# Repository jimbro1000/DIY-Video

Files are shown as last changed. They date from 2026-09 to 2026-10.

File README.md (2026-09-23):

# DIY Video #

The DIY Video project is an attempt to define a reusable video "chip" with
modular components. The concept is to limit the design to regular 74LS
ICs.

The goal is a design that can be plugged into most (if not all) 8-bit
computers.

The minimal design permits a system that can switch between a simple
text mode and bitmap mode with a usable screen resolution of 320x200 pixels.
Output is unterminated RGB that can be transformed into an appropriate
format as required

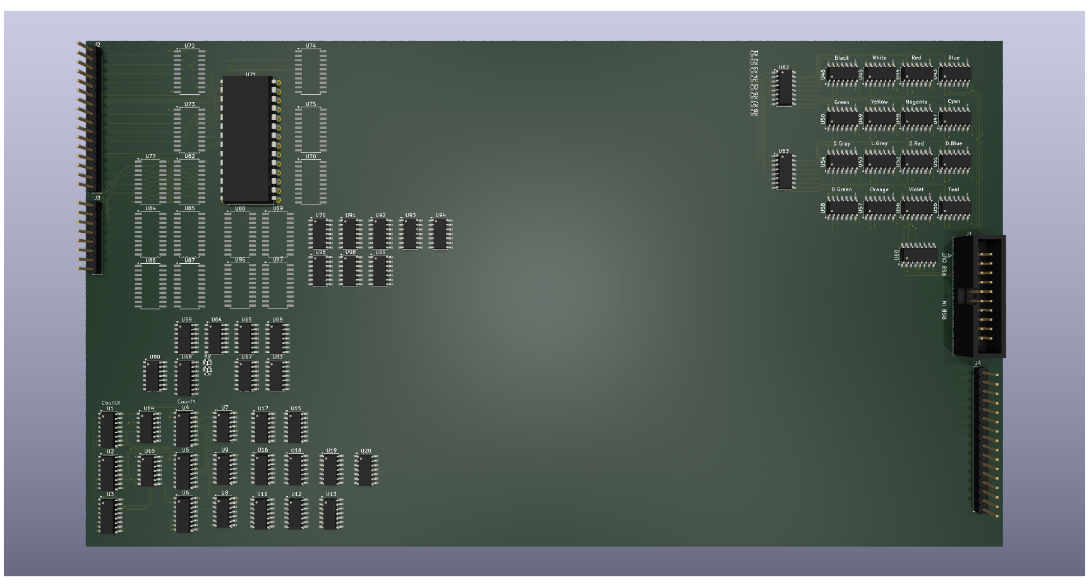
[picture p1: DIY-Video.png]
Render of PCB


## Design Concepts ##

Each major component of the video system is deliberately isolated so
that a change in one area should not require rework elsewhere. This rule
is broken in some places but is respected as much as possible

The core of the system is a pair of counters that track the X and Y 
position of the "beam". These counters are then used to define the
frame timing (sync and blank) and the viewport position on the screen.

The frame timing also controls what video source makes it to the output
as the sync and blank phases of the signal fall under timing control.

The bitmap renderer uses the pixel counters to generate a palette index
based on either a 1, 2 or 4 bit length value. The index is turned into
RGB using a separate pair of modules that generate 16 distinct RGB values
and a decoder that switches the RGB output between the 16 different
palette options

Independently to all this is the memory controller, actually a repeated
module that provisions different, parallel rendering mechanisms. From
the perspective of the video system each has its own address register
and can be accessed independently of the others - so the bitmap, tile
and sprite data can be operated separately without impacting the timing
of the other.

Externally the different blocks of memory needed to be mapped into the
hosts address space. To facilitate this the different memory blocks
are first selected by a device select signal and are then (optionally)
paged to ease the host burden. 

This approach makes the internal address very wide - each memory block is
a maximum of 32K and with distinct address buses and data buses the burden
for the video system is high but the length and distribution of those
buses can be minimised leaving just the palette values as the the 
interconnect rather than wide data and address buses

The current design respects five different addressable sub-devices
Bitmap memory  
Tile memory  
Sprite memory  
Font generator  
Control registers  

Only the bitmap and control registers are currently implemented.

The font generator in initial design iterations will be a simple eprom that
does not require external addressing

## Roadmap ##

### Stage 1 ###

The initial design stage is to define the hardware and interfaces, the broad
timing requirements and what modules are dependent. The goal is to achieve
a design that can be tested in self-contained modules, that together can
implement a basic bitmap based video generator.

### Stage 2 ###

The initial design will be verified and refined to prove that the modules work.
No attempt to integrate the modules will be attempted at this stage. Signal
and power requirements will be added to the design

### Stage 3 ###

Modules will be implemented as independent PCBs to be re-verified. A backplane
to integrate the modules will be needed with scope to extend the design to 
include other sub-systems

### Stage 4 ###

This is the first opportunity to integrate the entire set of modules defined.
To provide a usable display that can be verified the system will also need
to be integrated with a host computer to drive the video memory content

## Test Progress ##

### Simulation ###

* Position Counters (verilog, CRUMB)
* ViewPort (Verilog)
* Bitmap Data Counters (Verilog)

## License ##

This project is licensed under CC BY-SA 4.0
<https://creativecommons.org/licenses/by-sa/4.0/>

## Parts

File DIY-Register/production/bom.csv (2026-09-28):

Designator | Footprint | Quantity | Value | LCSC Part #
C1, C2 | 0603 | 2 | 10nF
D1, D2, D3, D4, D5, D6, D7, D8 | 0603 | 8 | LED_Small_Filled
J1 | PinHeader_1x10_P1.27mm_Vertical | 1 | Register0
J2 | PinHeader_1x10_P1.27mm_Vertical | 1 | XDBus
J3 | PinHeader_1x08_P1.27mm_Vertical | 1 | XDBus
RN1, RN2 | R_Array_Concave_4x0402 | 2 | 100R
U1 | SO-20_5.3x12.6mm_P1.27mm | 1 | 74LS374
U2 | SO-20_5.3x12.6mm_P1.27mm | 1 | 74LS244

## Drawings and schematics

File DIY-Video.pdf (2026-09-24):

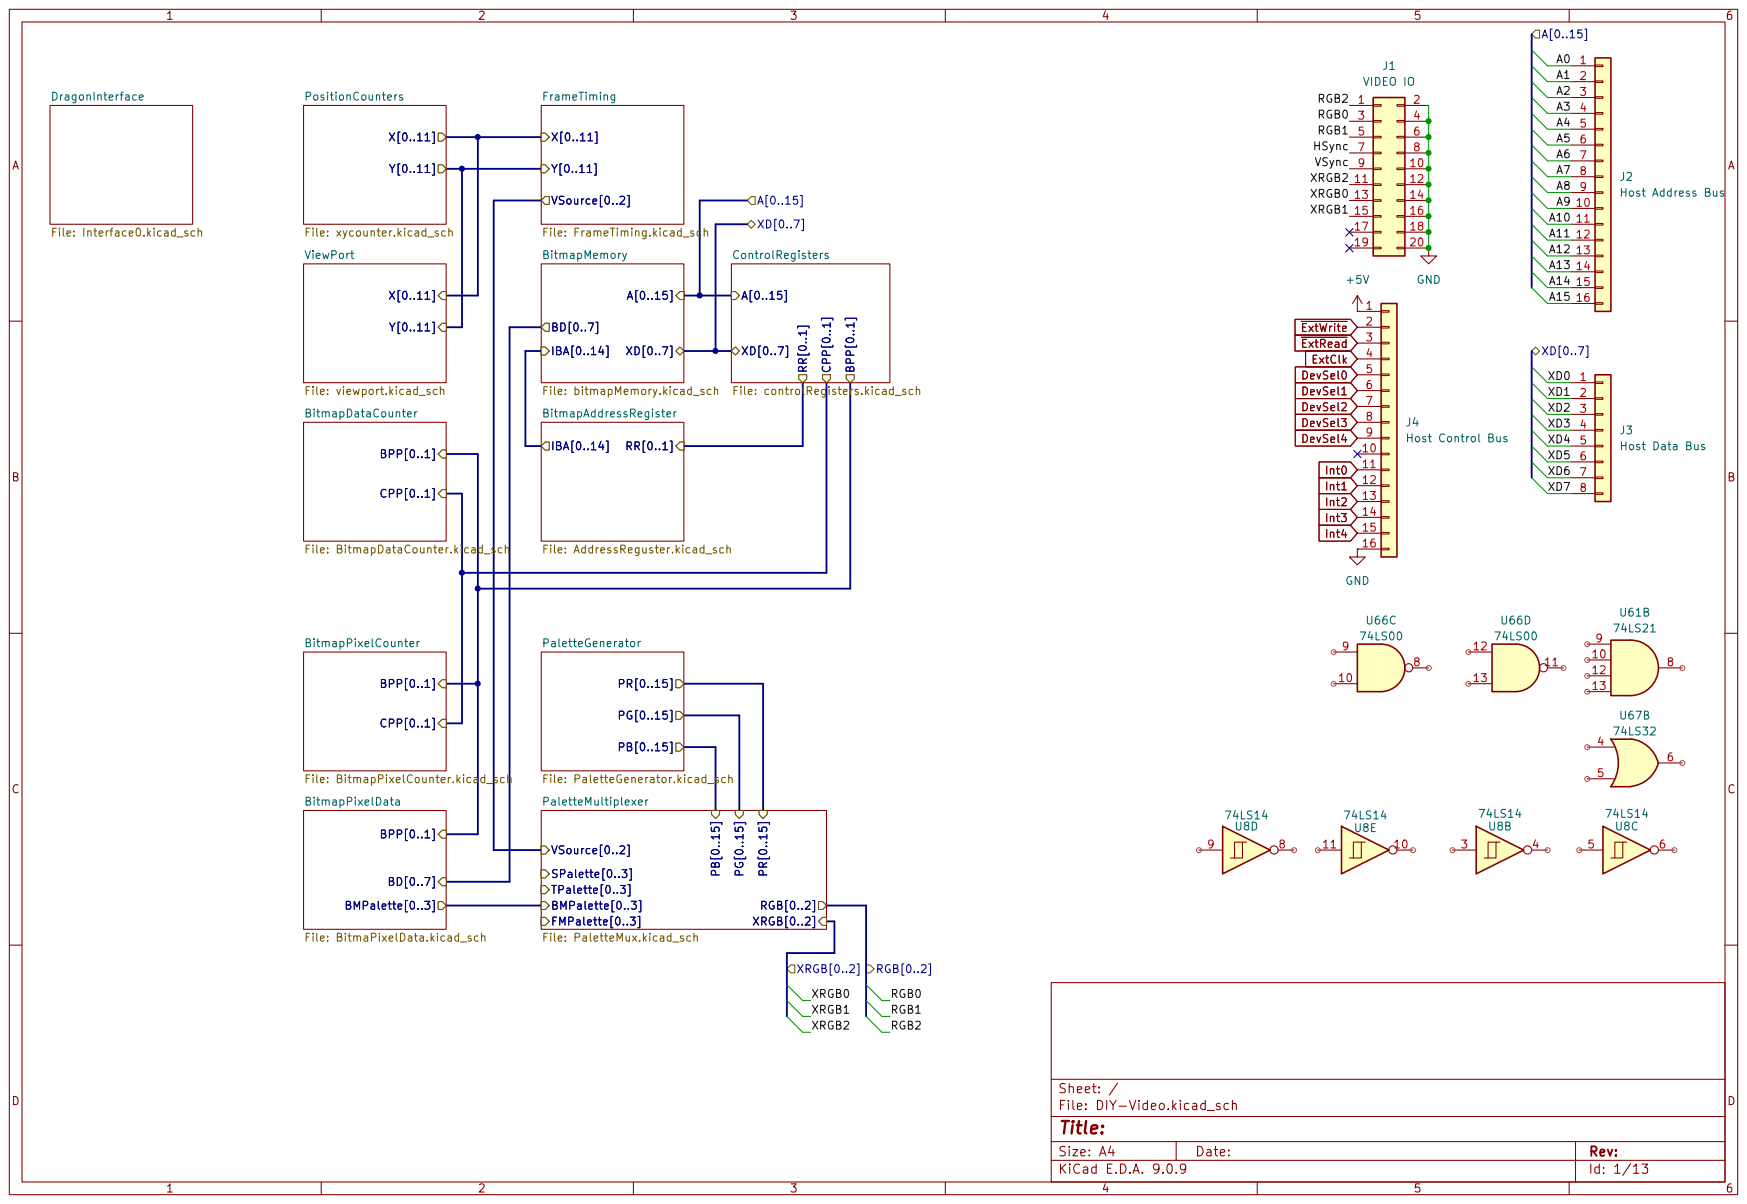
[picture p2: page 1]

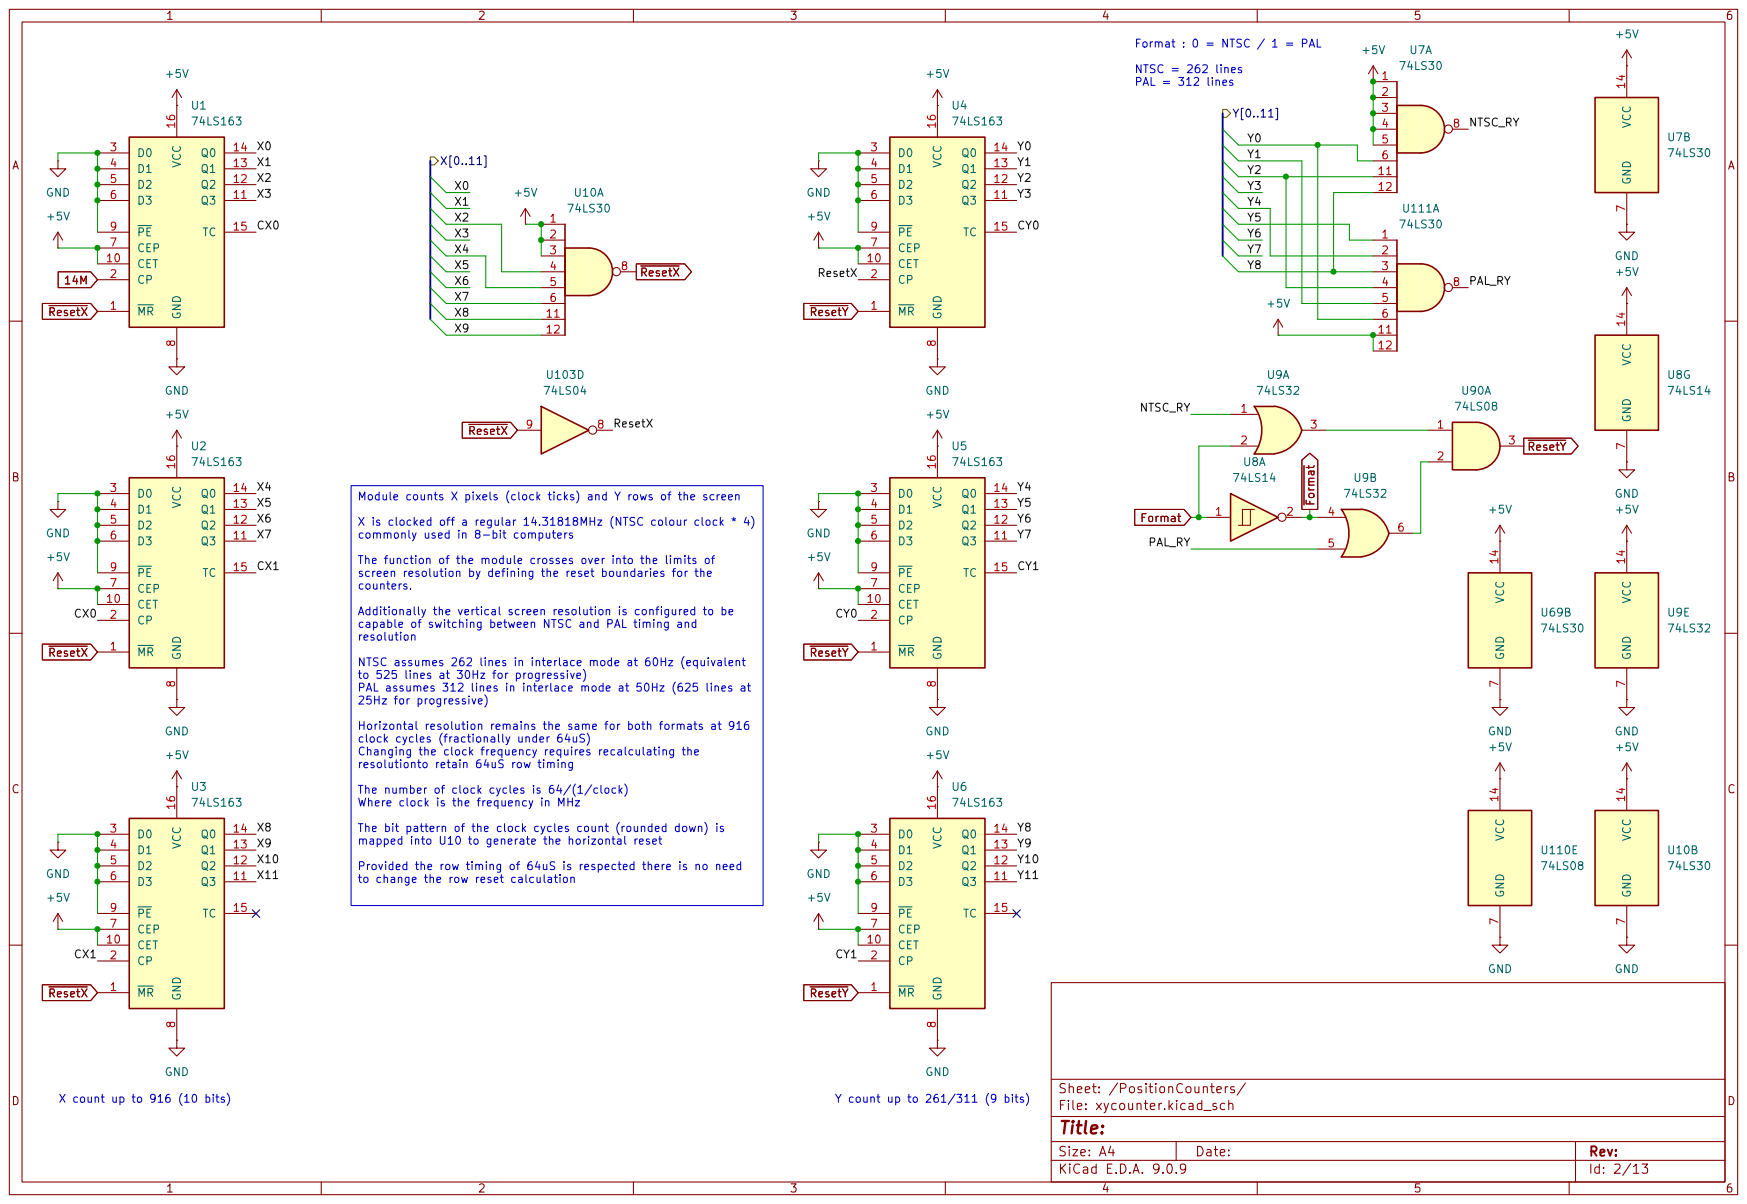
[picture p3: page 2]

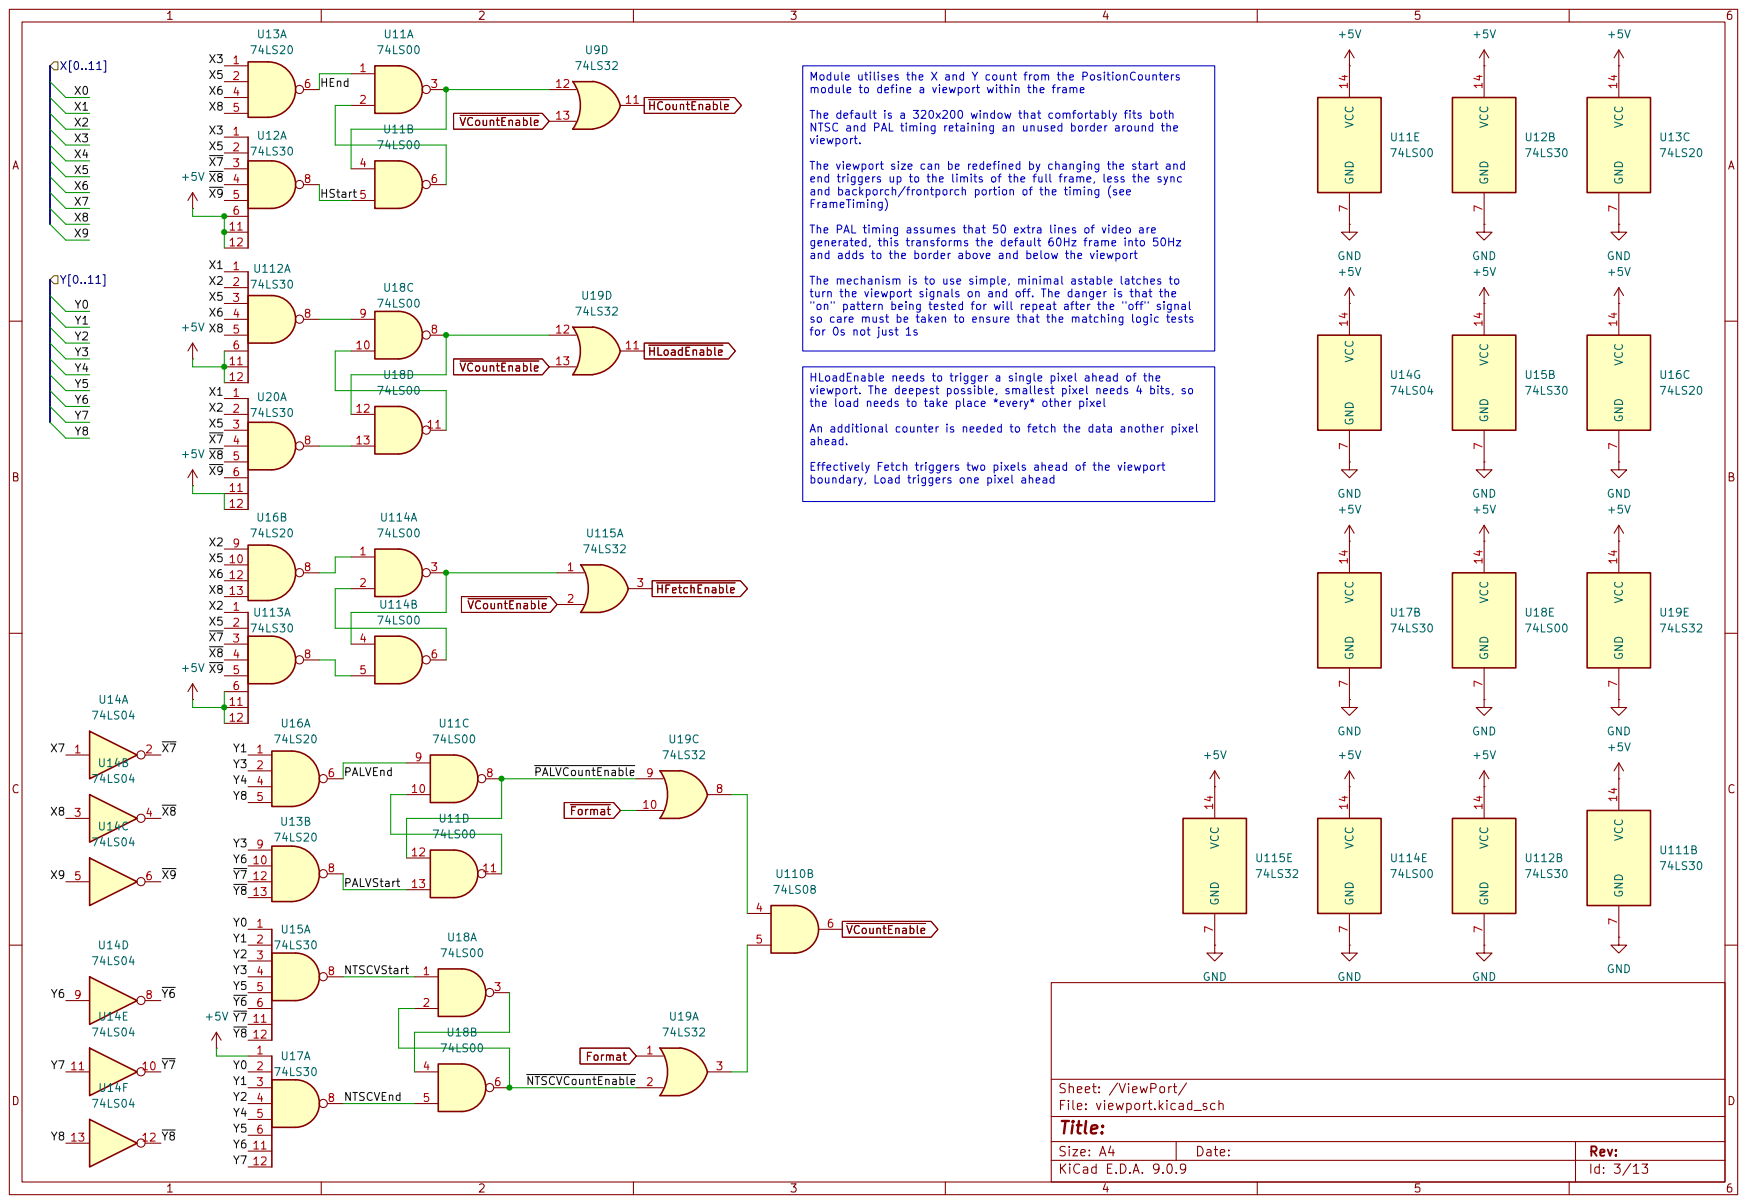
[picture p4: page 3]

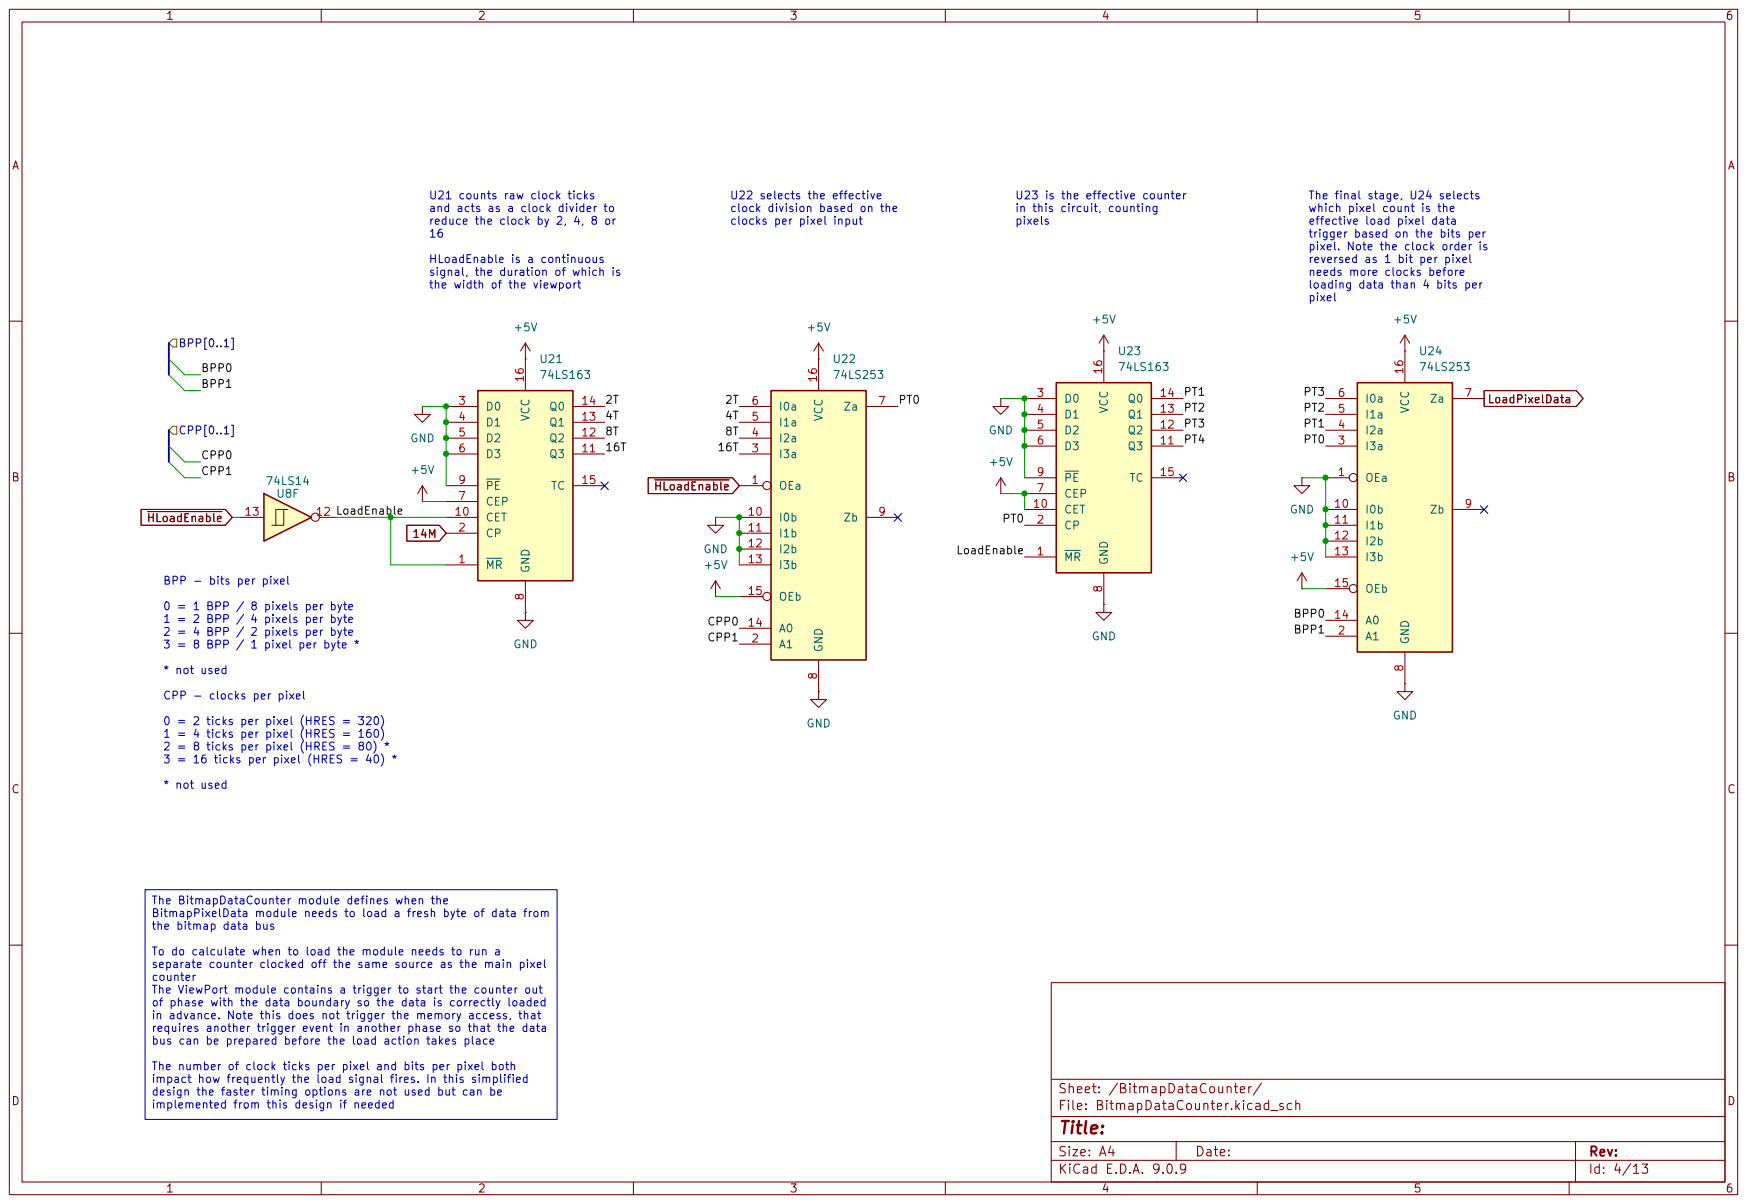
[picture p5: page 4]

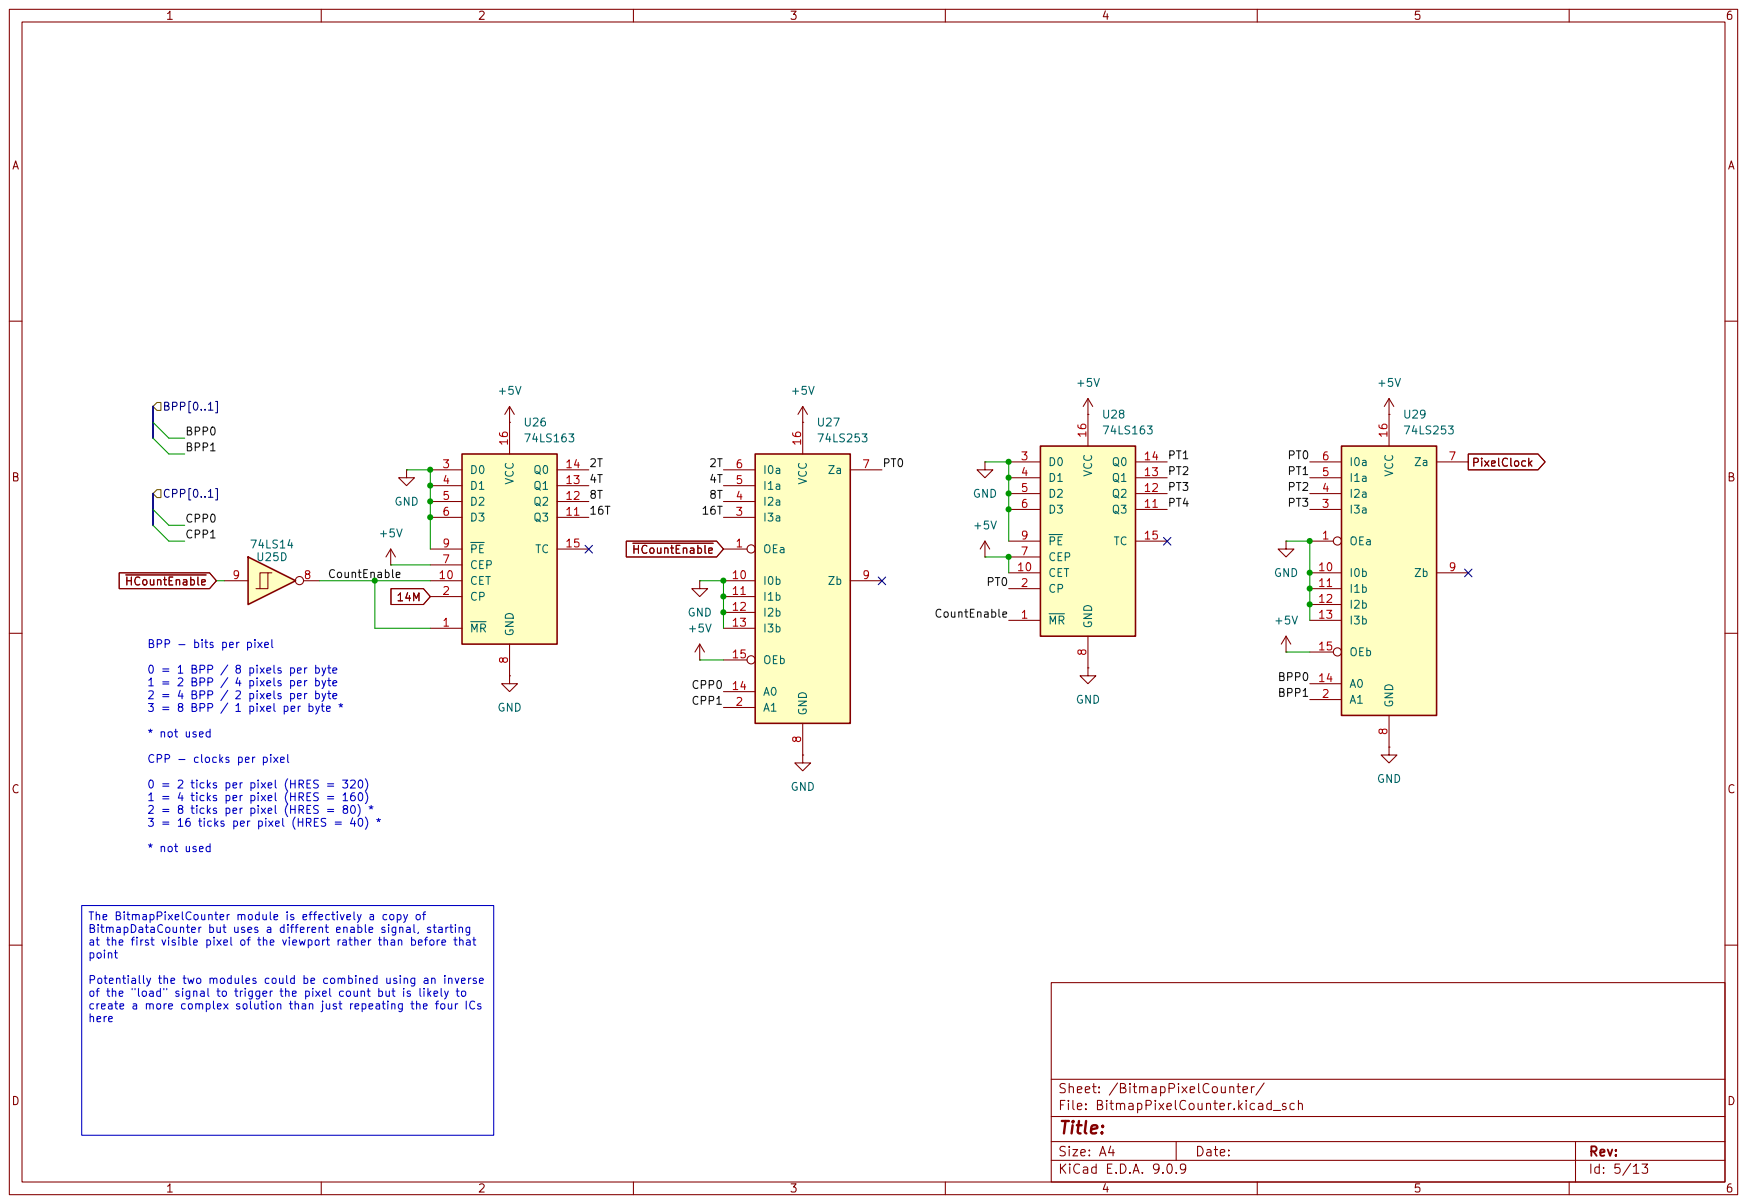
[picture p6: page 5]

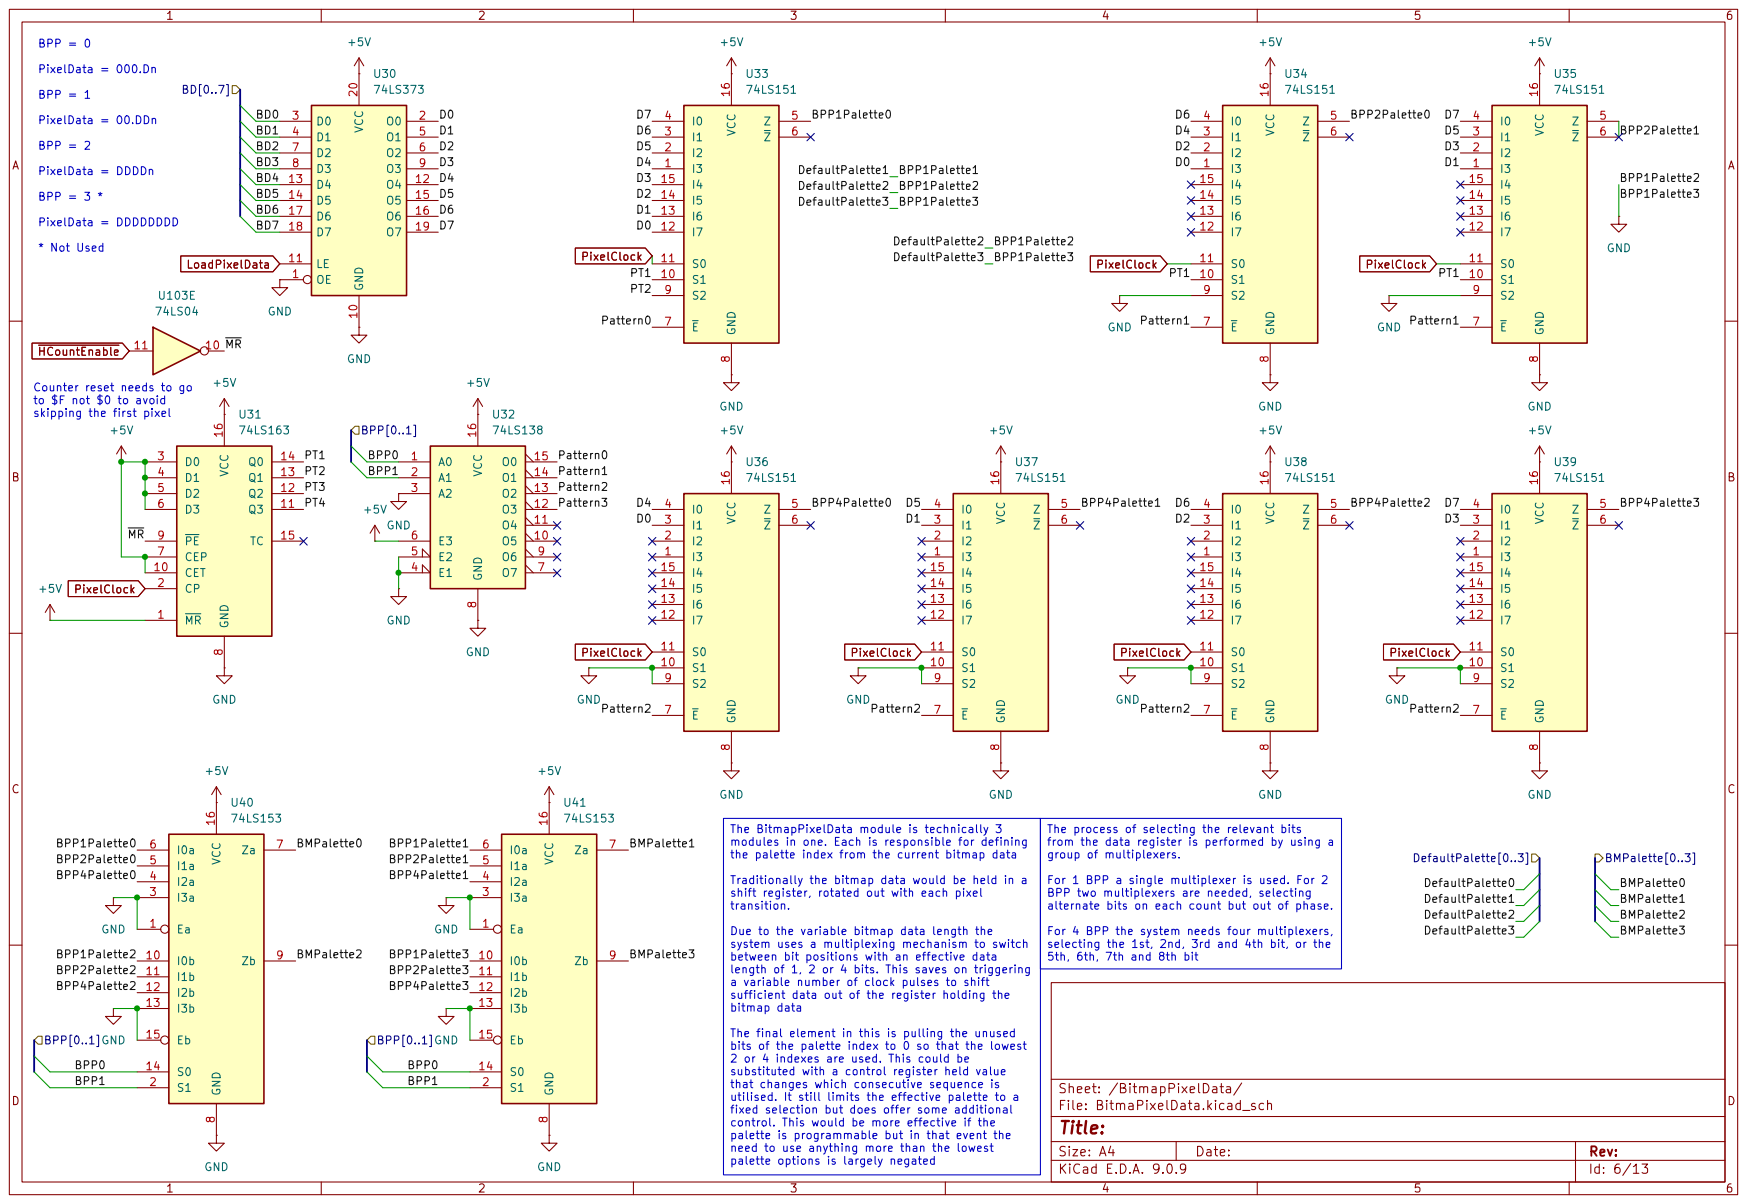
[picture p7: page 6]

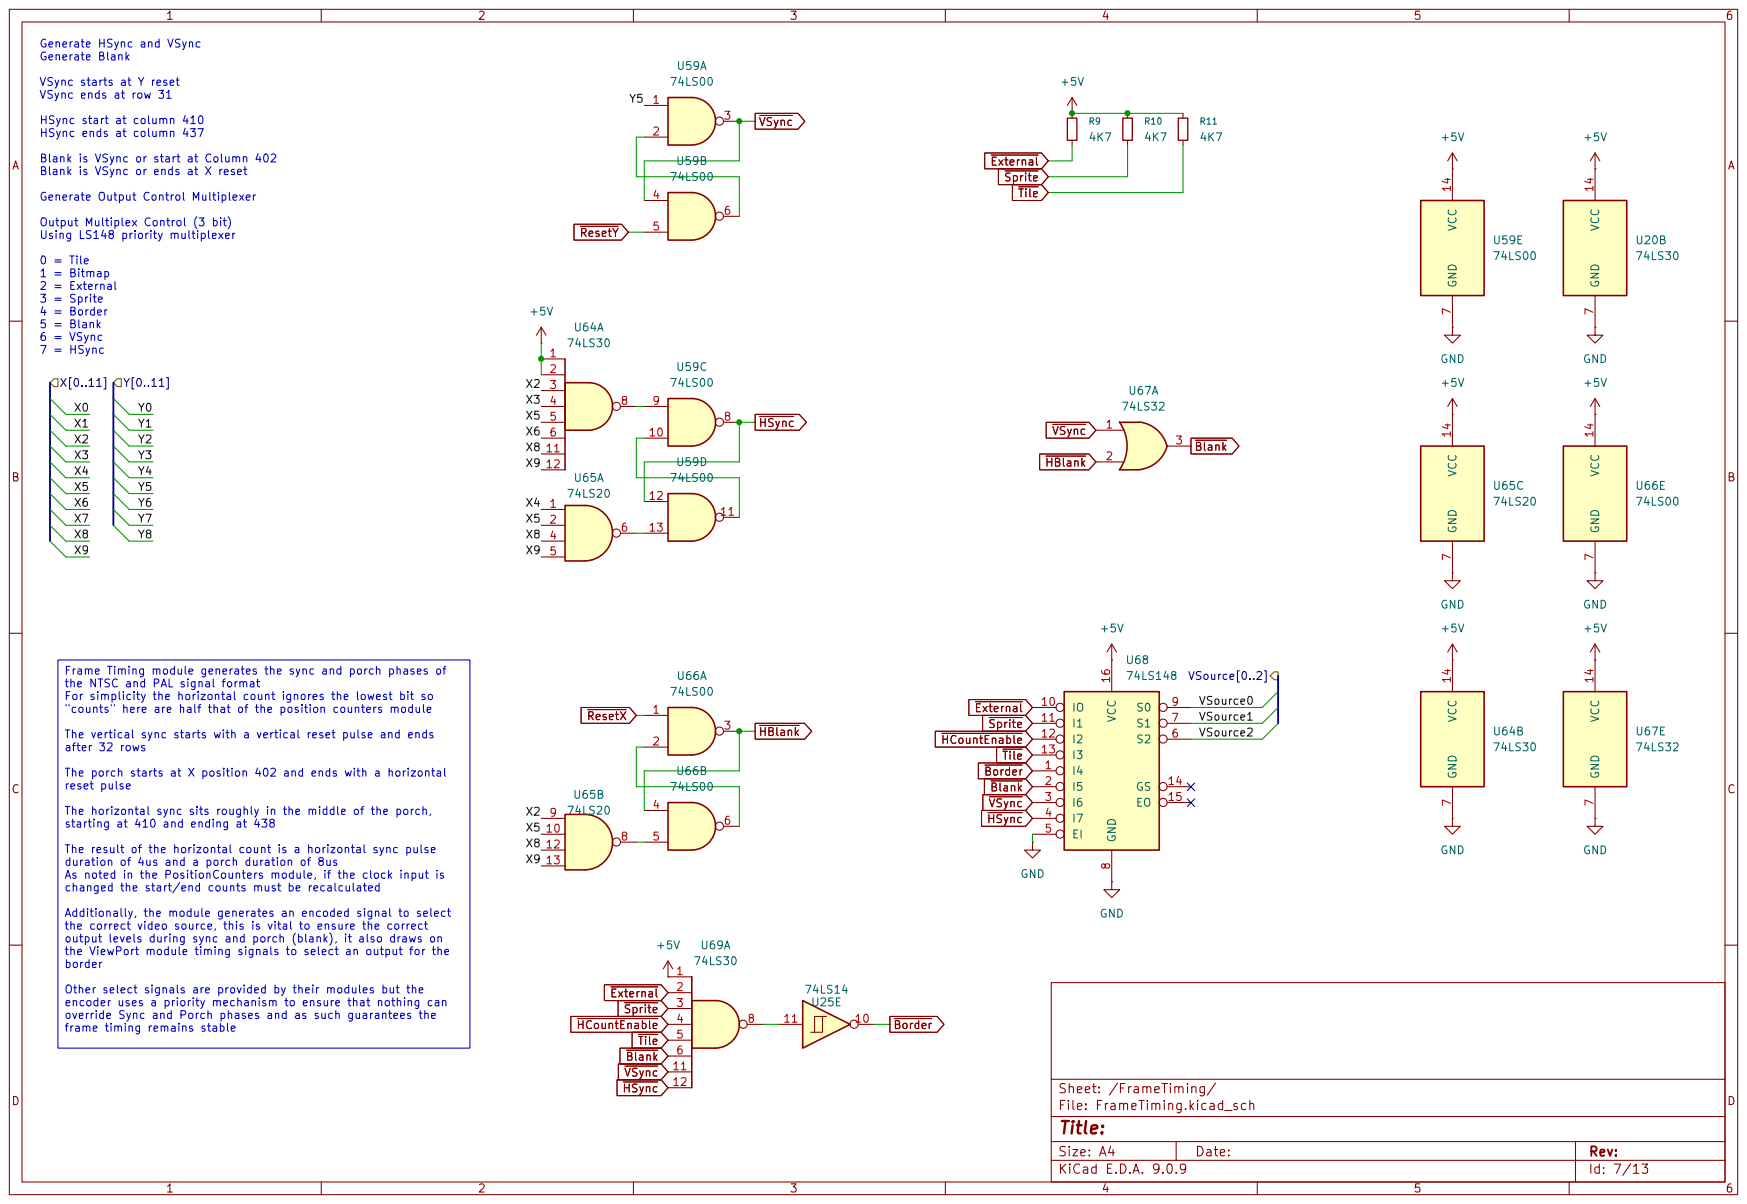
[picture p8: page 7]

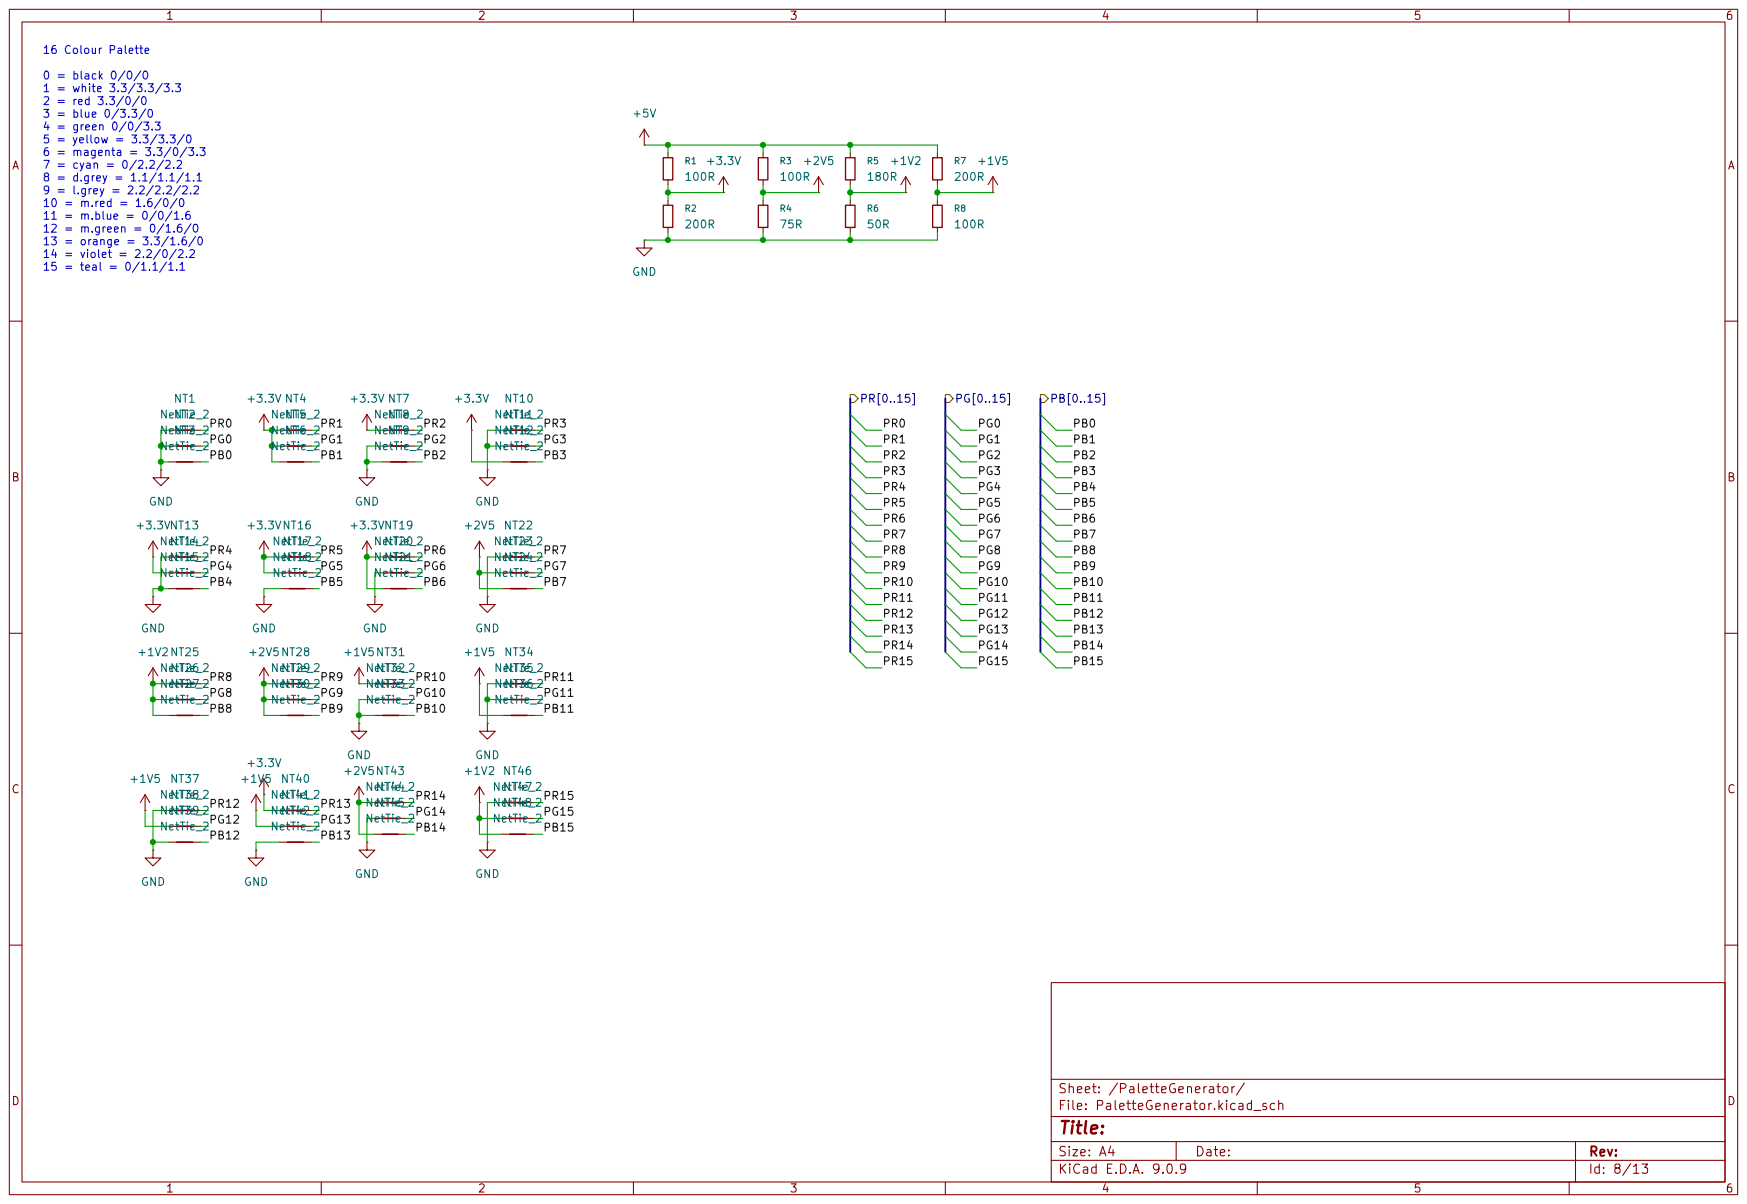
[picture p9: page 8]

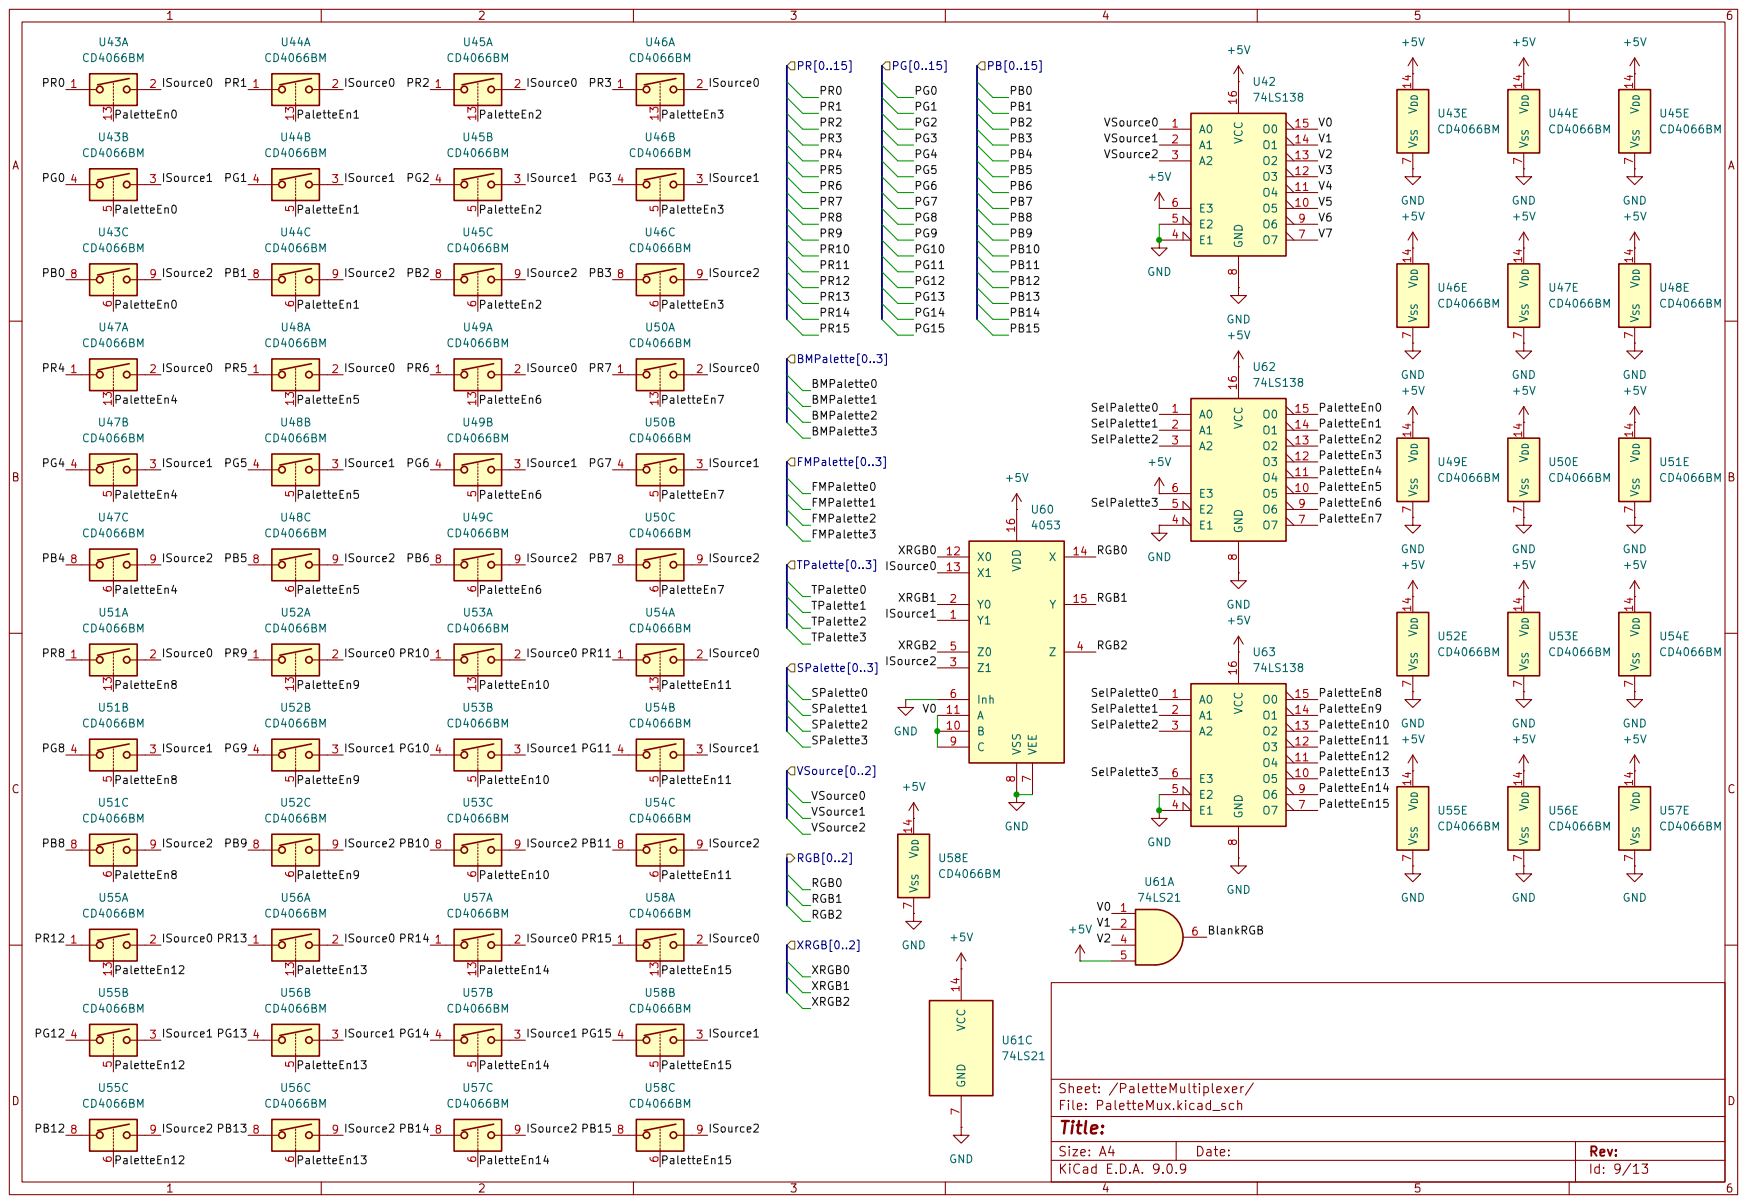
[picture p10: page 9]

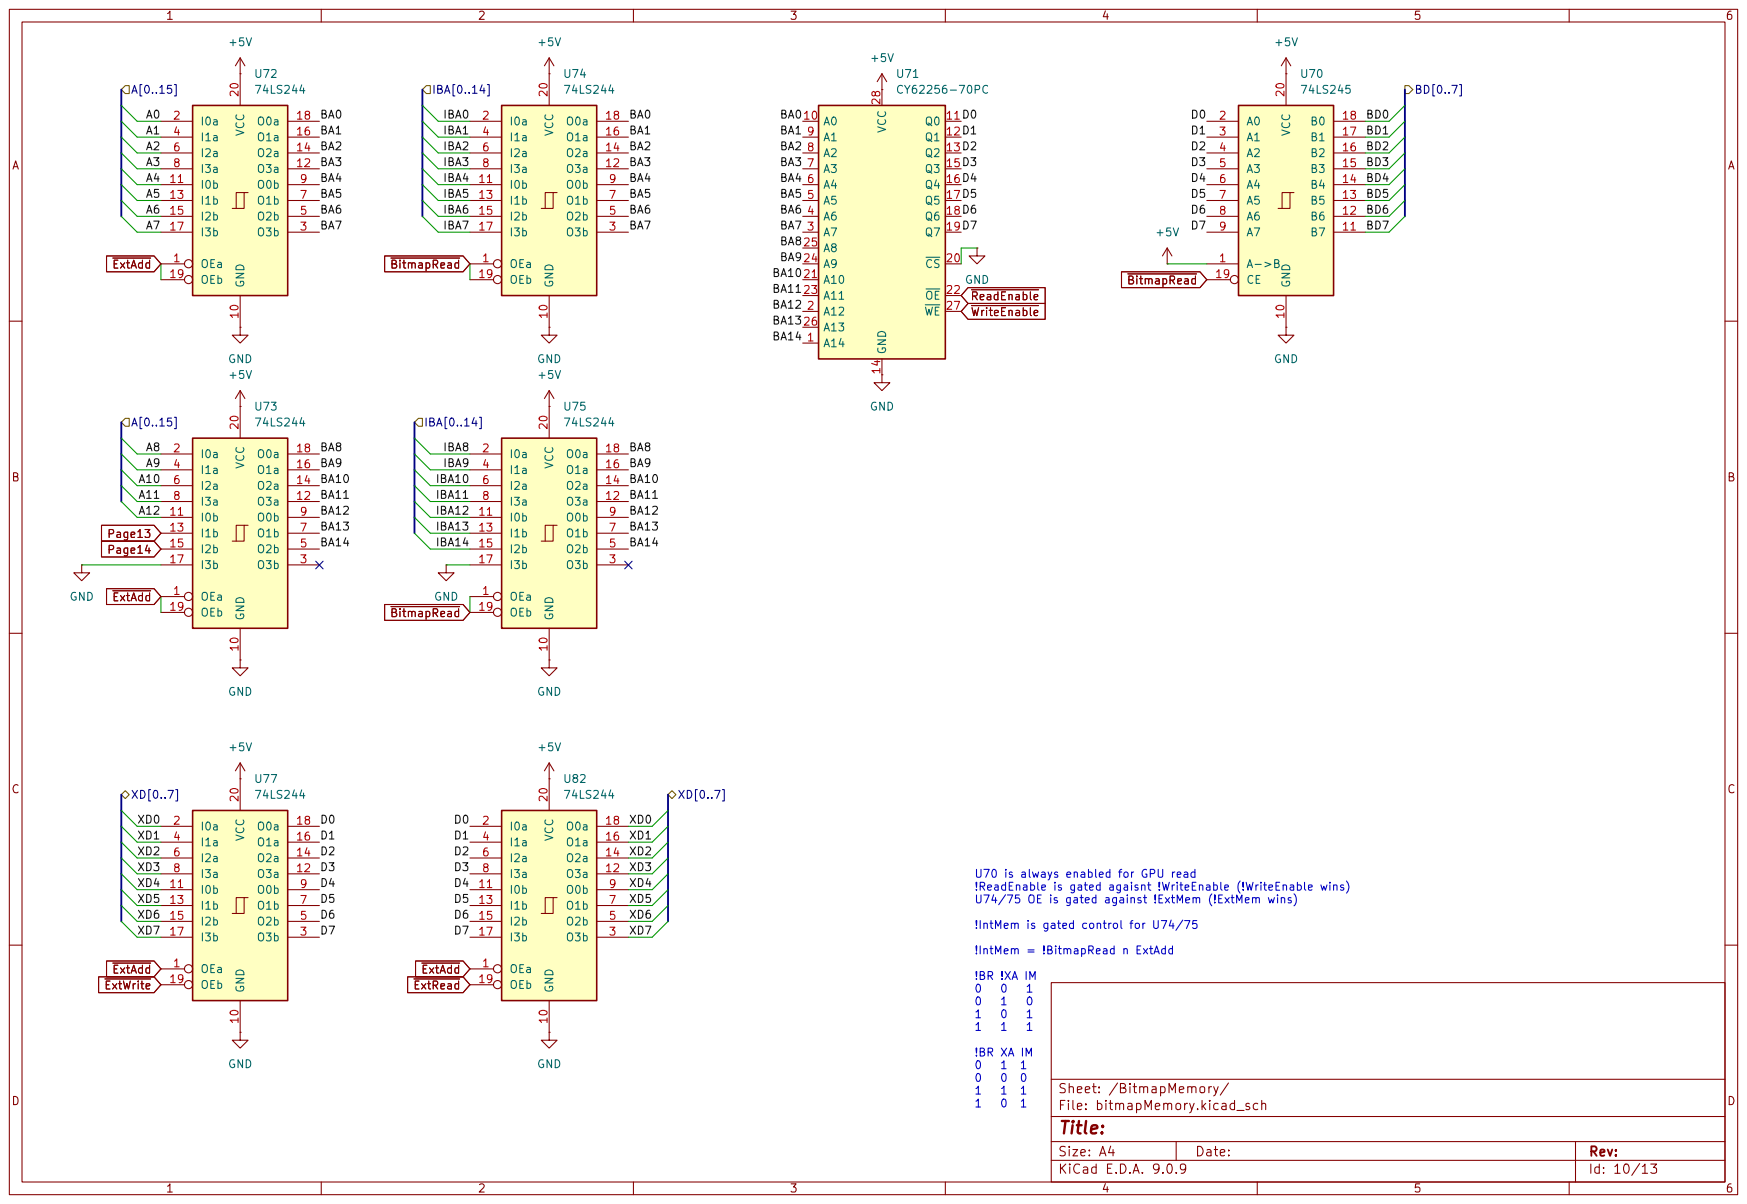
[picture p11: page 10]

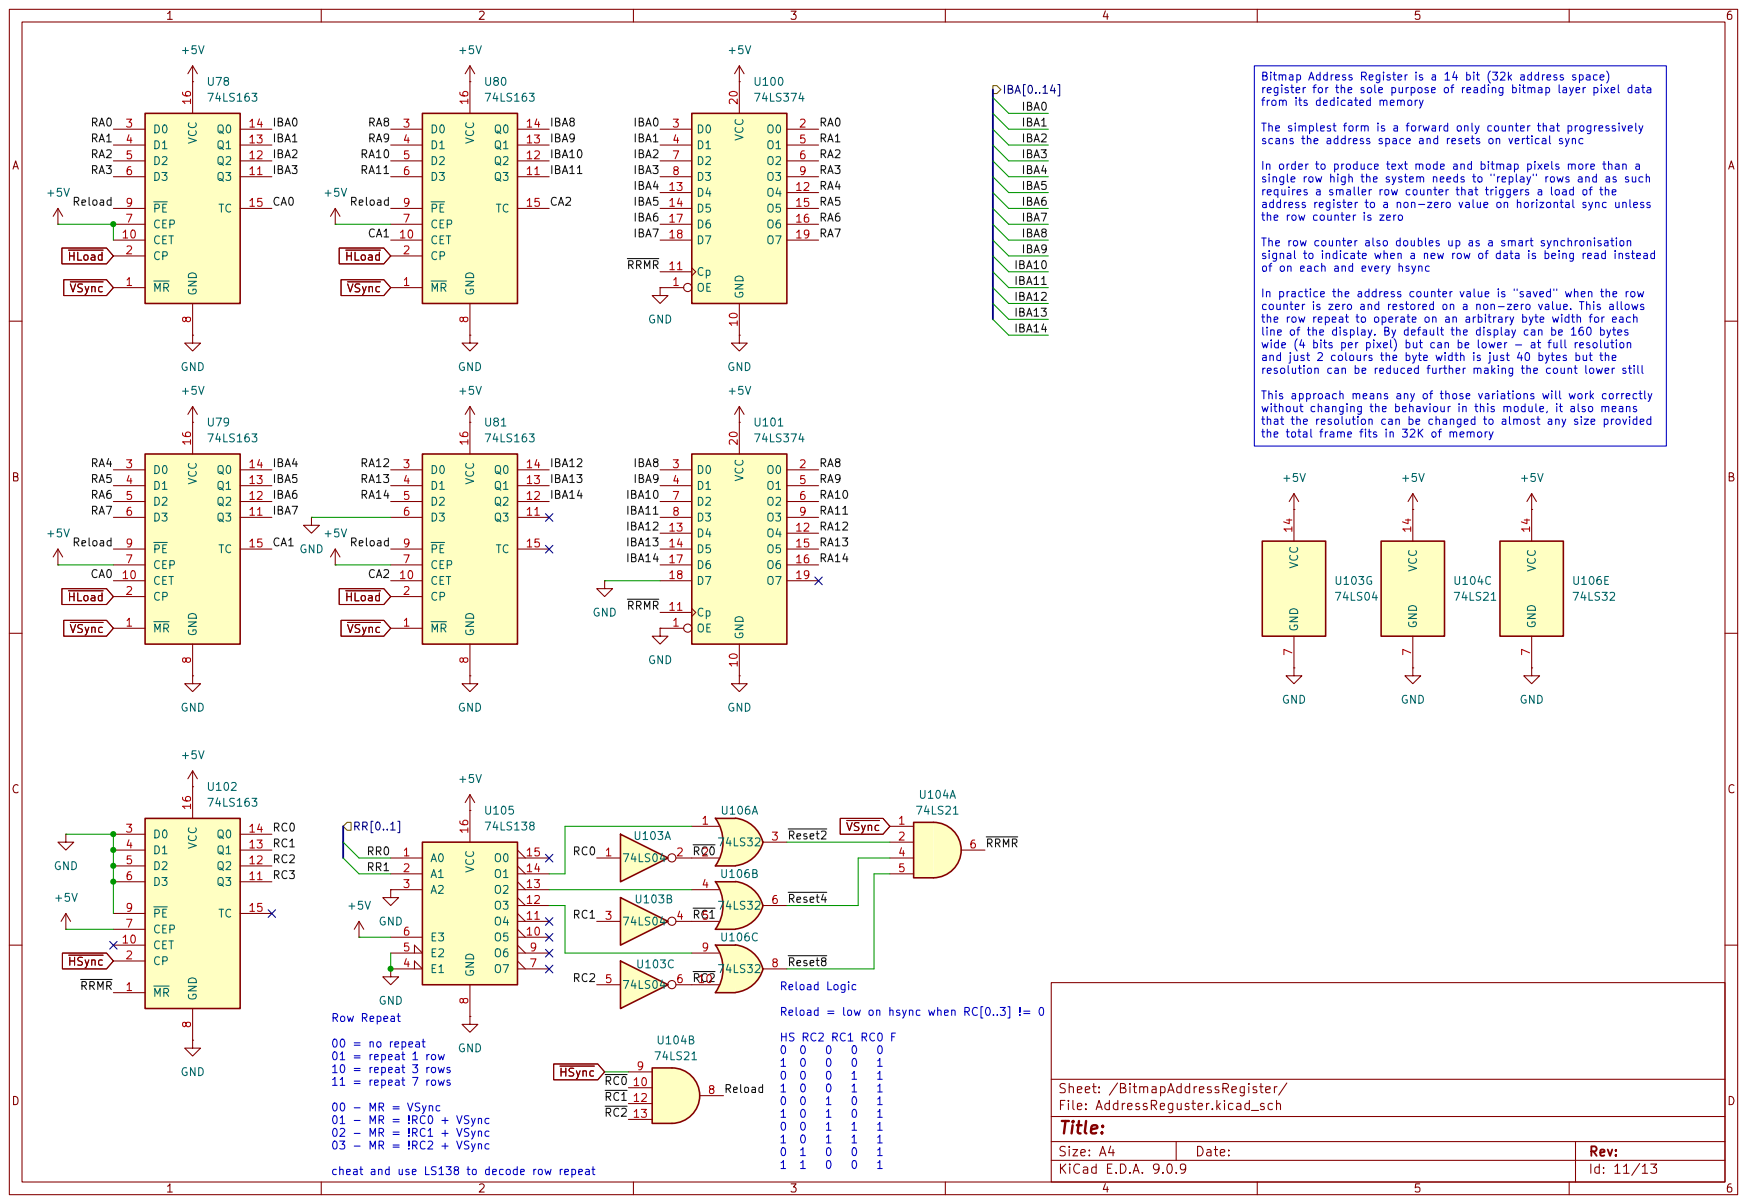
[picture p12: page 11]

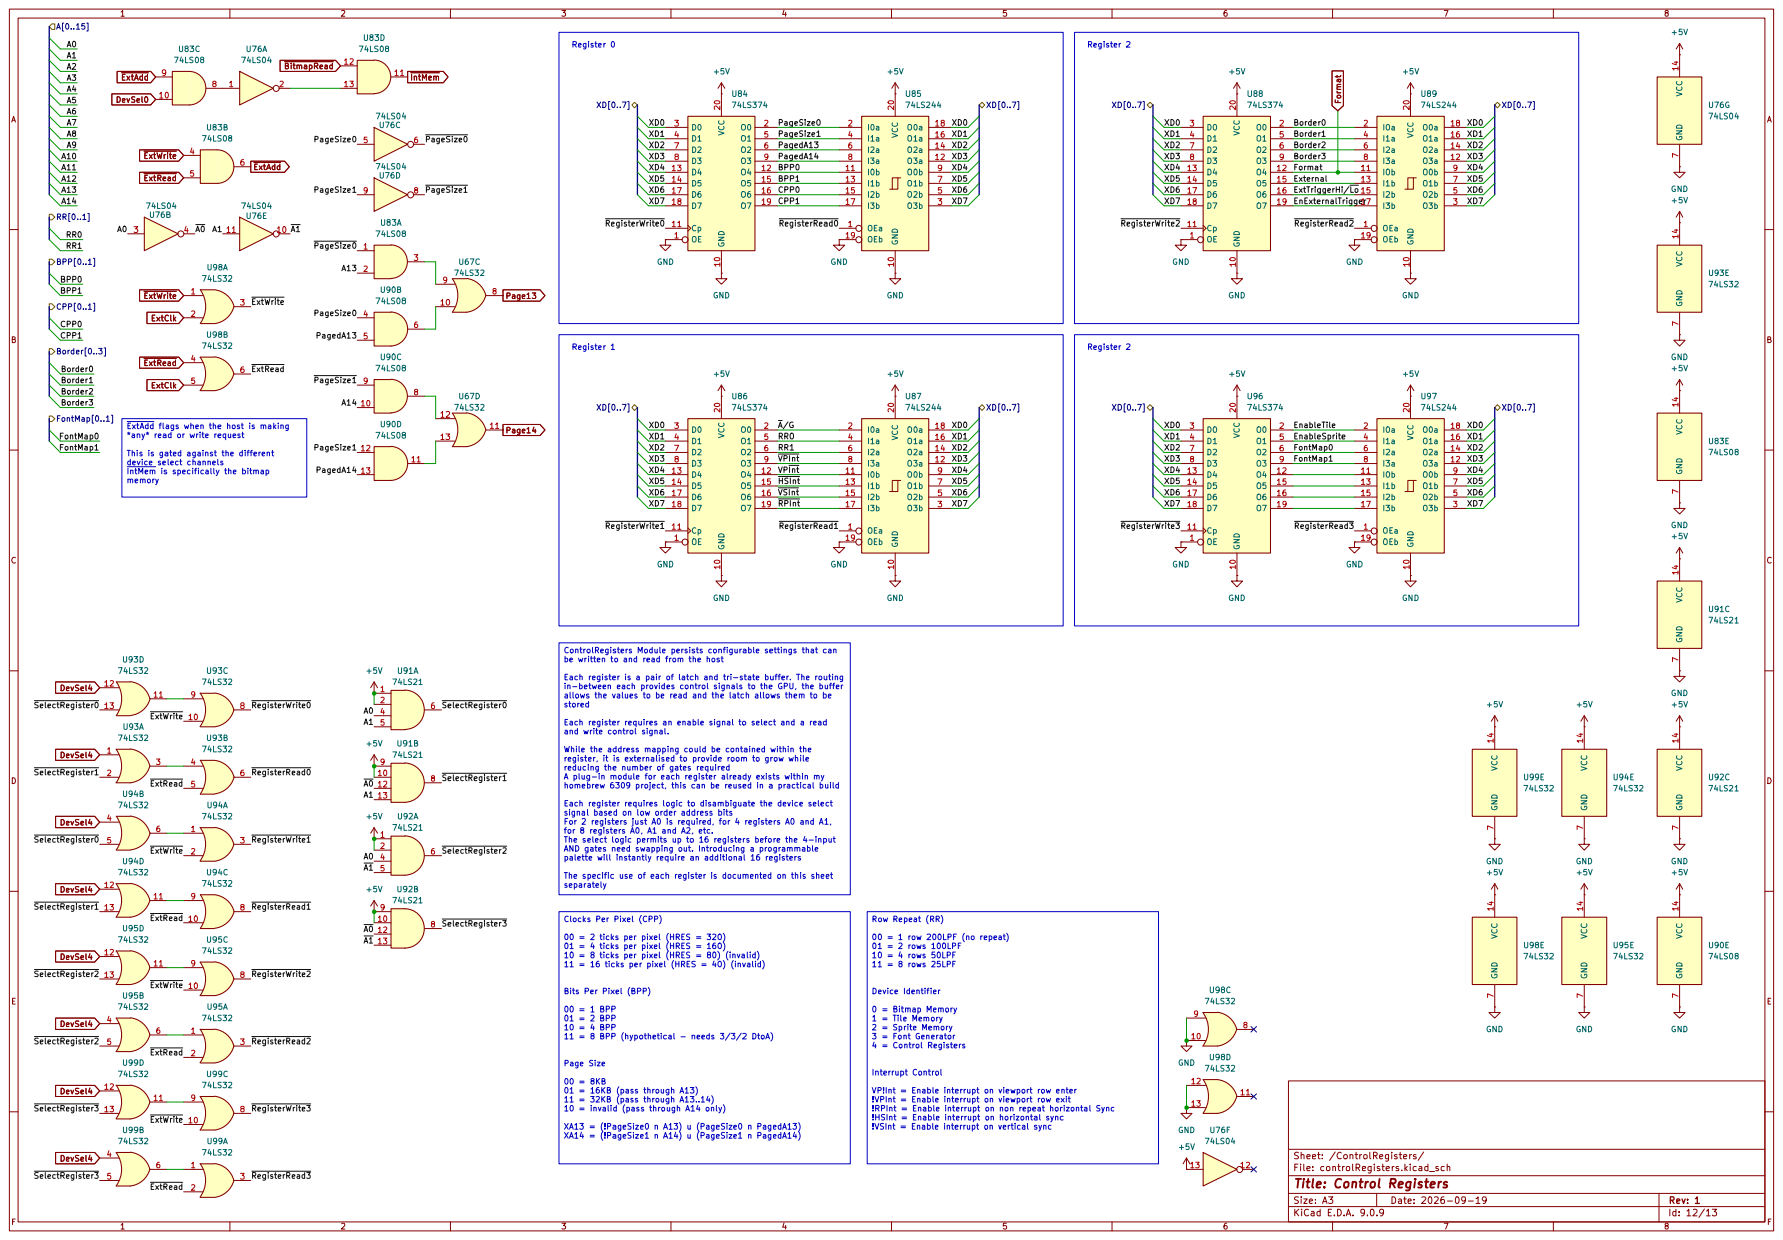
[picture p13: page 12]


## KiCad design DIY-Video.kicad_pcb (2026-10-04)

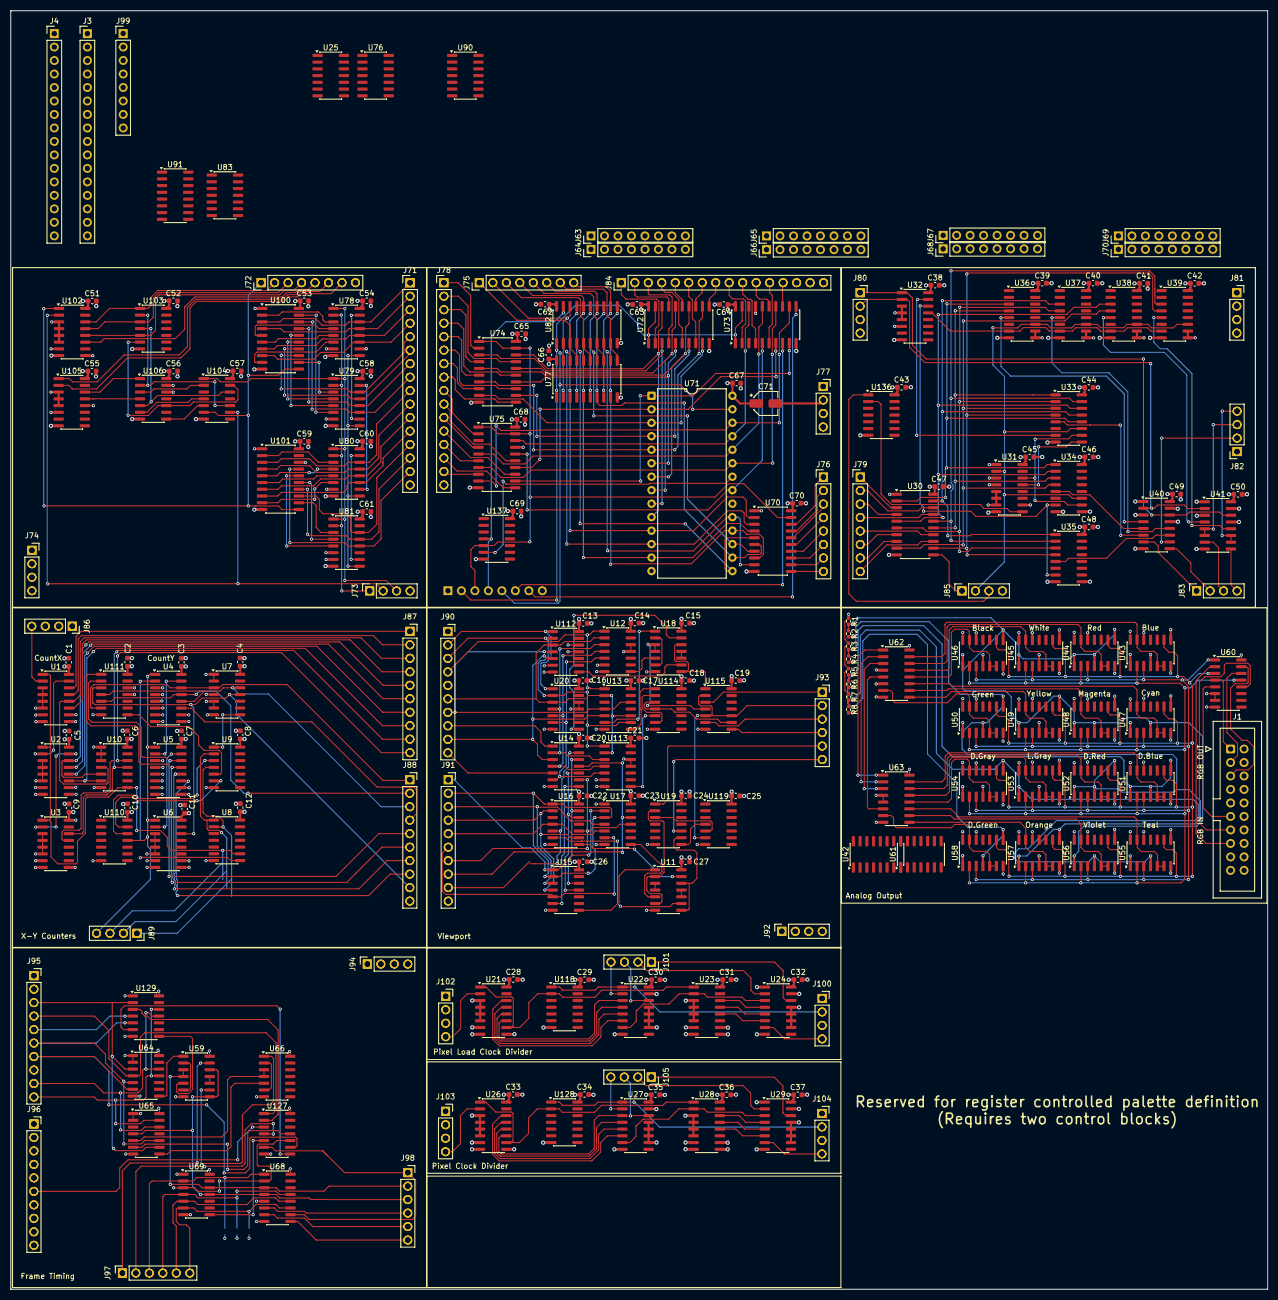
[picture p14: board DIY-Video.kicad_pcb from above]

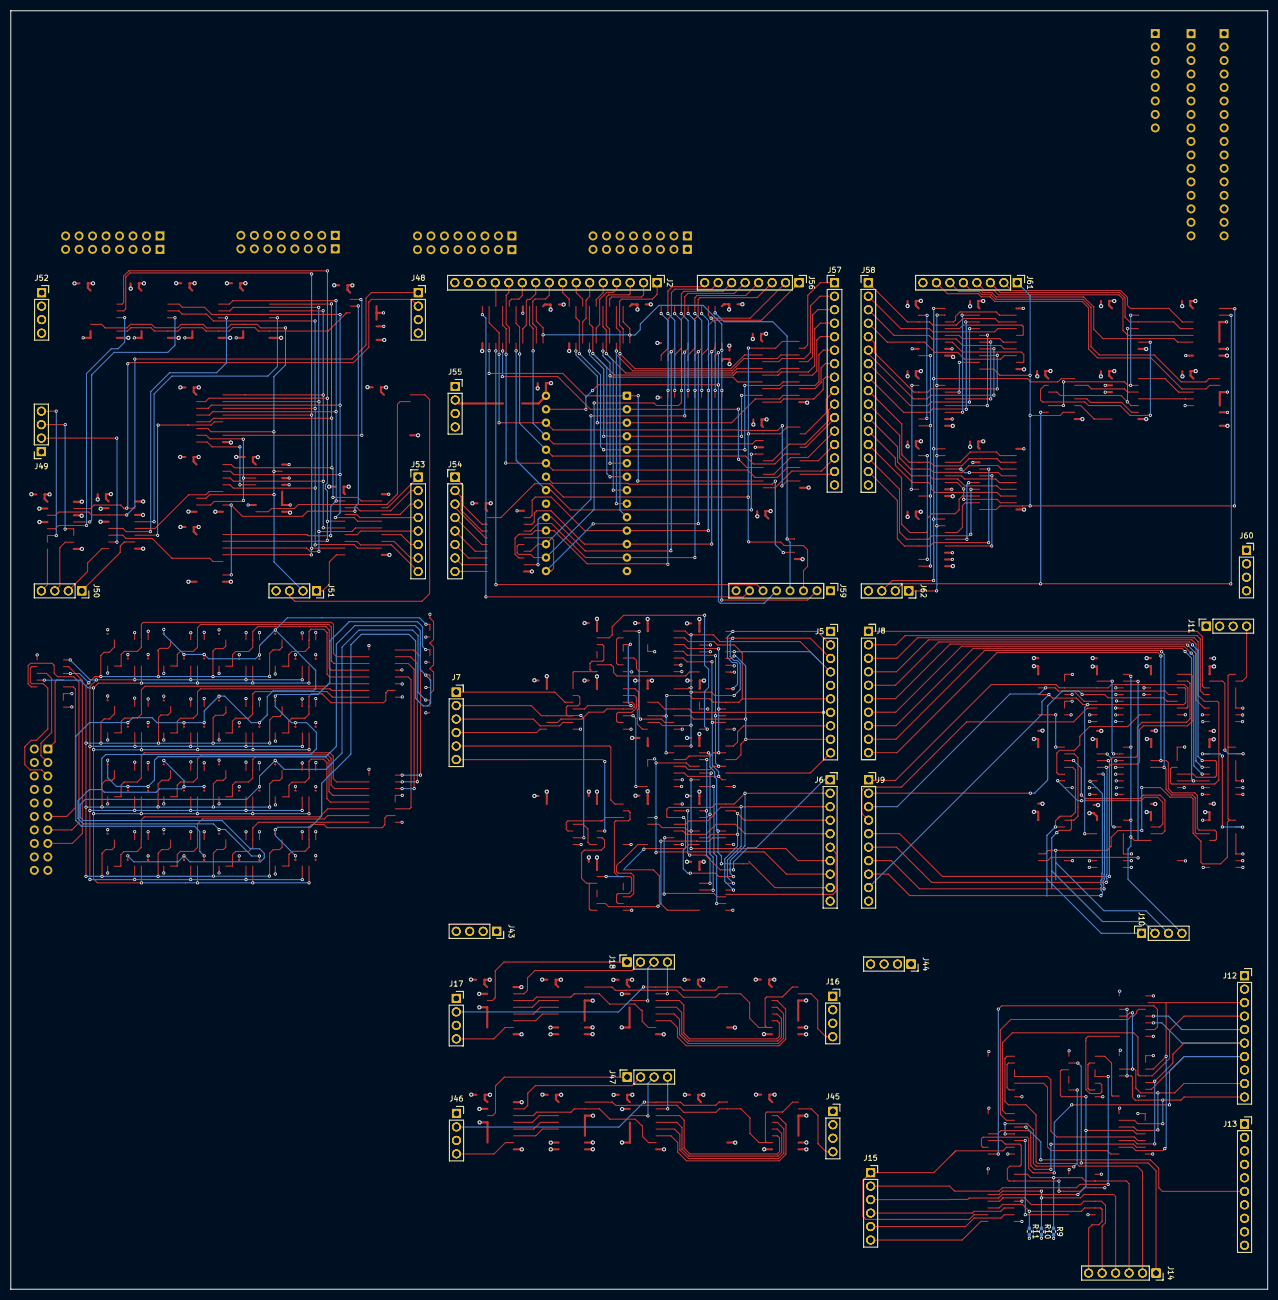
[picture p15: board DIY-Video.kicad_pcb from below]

Board: 4 copper layers, 236.8 x 240.9 mm, 315 parts (38 on the bottom side), 422 nets.

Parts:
C1, C2, C3, C4, C5, C6, C7, C8, C9, C10, C11, C12, C13, C14, C15, C16, C17, C18, C19, C20, C21, C22, C23, C24, C25, C26, C27, C28, C29, C30, C31, C32, C33, C34, C35, C36, C37, C38, C39, C40, C41, C42, C43, C44, C45, C46, C47, C48, C49, C50, C51, C52, C53, C54, C55, C56, C57, C58, C59, C60, C61, C62, C63, C64, C65, C66, C67, C68, C69, C70: 10nF; C_0603_1608Metric
C71: 4.7uF; CP_Elec_4x3
J1: VIDEO IO; IDC-Header_2x10_P2.54mm_Vertical
J2, J3, J84: Host Address Bus; PinHeader_1x16_P2.54mm_Vertical
J4: Host Control Bus; PinHeader_1x16_P2.54mm_Vertical
J5, J8, J12, J87, J90, J95: posX; PinSocket_1x10_P2.54mm_Vertical
J6, J9, J13, J88, J91, J96: posY; PinSocket_1x10_P2.54mm_Vertical
J7, J93: ViewportTriggers; PinSocket_1x06_P2.54mm_Vertical
J10, J89: PosResets; PinSocket_1x04_P2.54mm_Vertical
J11, J16, J45, J52, J81, J86, J102, J103: Power and Clock; PinSocket_1x04_P2.54mm_Vertical
J14, J97: TimingTriggers; PinSocket_1x06_P2.54mm_Vertical
J15, J98: ViewportOutput; PinSocket_1x06_P2.54mm_Vertical
J17, J46, J51, J62, J73, J85, J100, J104: Triggers; PinSocket_1x04_P2.54mm_Vertical
J18, J47, J48, J80, J101, J105: OpMode; PinSocket_1x04_P2.54mm_Vertical
J43, J44, J55, J60, J74, J77, J92, J94: Power; PinSocket_1x04_P2.54mm_Vertical
J49, J82: Default Palette; PinSocket_1x04_P2.54mm_Vertical
J50, J83: Output Palette; PinSocket_1x04_P2.54mm_Vertical
J53, J54, J76, J79: BDBus; PinHeader_1x08_P2.54mm_Vertical
J56, J75, J99: XDBus; PinHeader_1x08_P2.54mm_Vertical
J57, J58, J71, J78: BitmapAddress; PinHeader_1x16_P2.54mm_Vertical
J59: Control; PinHeader_1x08_P2.54mm_Vertical
J61, J72: RowCountControl; PinHeader_1x08_P2.54mm_Vertical
J63: Reg0; PinHeader_1x08_P2.54mm_Vertical
J64: Reg1; PinHeader_1x08_P2.54mm_Vertical
J65: Reg2; PinHeader_1x08_P2.54mm_Vertical
J66: Reg3; PinHeader_1x08_P2.54mm_Vertical
J67: Reg4; PinHeader_1x08_P2.54mm_Vertical
J68: Reg5; PinHeader_1x08_P2.54mm_Vertical
J69: Reg6; PinHeader_1x08_P2.54mm_Vertical
J70: Reg7; PinHeader_1x08_P2.54mm_Vertical
NT1, NT2, NT3, NT4, NT5, NT6, NT7, NT8, NT9, NT10, NT11, NT12, NT13, NT14, NT15, NT16, NT17, NT18, NT19, NT20, NT21, NT22, NT23, NT24, NT25, NT26, NT27, NT28, NT29, NT30, NT31, NT32, NT33, NT34, NT35, NT36, NT37, NT38, NT39, NT40, NT41, NT42, NT43, NT44, NT45, NT46, NT47, NT48: NetTie_2; NetTie-2_SMD_Pad0.4mm
R1, R3, R8: 100R; R_0402_1005Metric_Pad0.72x0.64mm_HandSolder
R2, R7: 200R; R_0402_1005Metric_Pad0.72x0.64mm_HandSolder
R4: 75R; R_0402_1005Metric_Pad0.72x0.64mm_HandSolder
R5: 180R; R_0402_1005Metric_Pad0.72x0.64mm_HandSolder
R6: 50R; R_0402_1005Metric_Pad0.72x0.64mm_HandSolder
R9, R10, R11: 4K7; R_0402_1005Metric_Pad0.72x0.64mm_HandSolder
U1, U2, U3, U4, U5, U6, U21, U23, U26, U28, U31, U78, U79, U80, U81, U102: 74LS163; SOIC-16_3.9x9.9mm_P1.27mm
U7, U10, U12, U15, U17, U20, U64, U69, U111, U112, U113, U129: 74LS30; SO-14_3.9x8.65mm_P1.27mm
U8, U14, U76: 74LS04; SO-14_3.9x8.65mm_P1.27mm
U9, U19, U115: 74LS32; SO-14_3.9x8.65mm_P1.27mm
U11, U18, U59, U66, U114: 74LS00; SO-14_3.9x8.65mm_P1.27mm
U13, U16, U65: 74LS20; SO-14_3.9x8.65mm_P1.27mm
U22, U24, U27, U29: 74LS253; SOIC-16_3.9x9.9mm_P1.27mm
U25, U106: 74LS32; SOIC-14_3.9x8.7mm_P1.27mm
U30: 74LS373; SO-20_5.3x12.6mm_P1.27mm
U32, U42, U62, U63, U105: 74LS138; SOIC-16_3.9x9.9mm_P1.27mm
U33, U34, U35, U36, U37, U38, U39: 74LS151; SOIC-16_3.9x9.9mm_P1.27mm
U40, U41: 74LS153; SOIC-16_3.9x9.9mm_P1.27mm
U43, U44, U45, U46, U47, U48, U49, U50, U51, U52, U53, U54, U55, U56, U57, U58: CD4066BM; SO-14_3.9x8.65mm_P1.27mm
U60: 4053; SOIC-16_3.9x9.9mm_P1.27mm
U61: 74LS21; SO-14_3.9x8.65mm_P1.27mm
U68: 74LS148; SOIC-16_3.9x9.9mm_P1.27mm
U70: 74LS245; SO-20_5.3x12.6mm_P1.27mm
U71: CY62256-70PC; DIP-28_W15.24mm
U72, U73, U74, U75, U77, U82: 74LS244; SO-20_5.3x12.6mm_P1.27mm
U83, U90, U110: 74LS08; SO-14_3.9x8.65mm_P1.27mm
U91: 74ALS138; SOIC-16_3.9x9.9mm_P1.27mm
U100, U101: 74LS374; SO-20_5.3x12.6mm_P1.27mm
U103, U118, U127, U128, U136: 74LS04; SOIC-14_3.9x8.7mm_P1.27mm
U104: 74LS21; SOIC-14_3.9x8.7mm_P1.27mm
U119, U137: 74LS08; SOIC-14_3.9x8.7mm_P1.27mm

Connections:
14M: J11.4, J16.4, J45.4, J86.4, J102.4, J103.4, U1.2 (CP), U21.2 (CP), U26.2 (CP)
+1V2: NT25.1, NT26.1, NT27.1, NT47.1, NT48.1, R5.2, R6.1
+1V5: NT31.1, NT36.1, NT38.1, NT41.1, R7.2, R8.1
+2V5: NT23.1, NT24.1, NT28.1, NT29.1, NT30.1, NT43.1, NT45.1, R3.2, R4.1
+3.3V: NT4.1, NT5.1, NT6.1, NT7.1, NT12.1, NT14.1, NT16.1, NT17.1, NT19.1, NT21.1, NT40.1, R1.2, R2.1
+5V: C1.1, C2.1, C3.1, C4.1, C5.1, C6.1, C7.1, C8.1, C9.1, C10.1, C11.1, C12.1, C13.1, C14.1, C15.1, C16.1, C17.1, C18.1, C19.1, C20.1, C21.1, C22.1, C23.1, C24.1, C25.1, C26.1, C27.1, C28.1, C29.1, C30.1, C31.1, C32.1, C33.1, C34.1, C35.1, C36.1, C37.1, C38.1, C39.1, C40.1, C41.1, C42.1, C43.1, C44.1, C45.1, C46.1, C47.1, C48.1, C49.1, C50.1, C51.1, C52.1, C53.1, C54.1, C55.1, C56.1, C57.1, C58.1, C59.1, C60.1, C61.1, C62.1, C63.1, C64.1, C65.1, C66.1, C67.1, C68.1, C69.1, C70.1, C71.1, J4.1, J11.1, J16.1, J43.1, J43.4, J44.1, J44.4, J45.1, J52.1, J55.1, J55.4, J60.1, J60.4, J74.1, J74.4, J77.1, J77.4, J81.1, J86.1, J92.1, J92.4, J94.1, J94.4, J102.1, J103.1, R1.1, R3.1, R5.1, R7.1, U1.7 (CEP), U1.10 (CET), U1.16 (VCC), U2.7 (CEP), U2.10 (CET), U2.16 (VCC), U3.7 (CEP), U3.10 (CET), U3.16 (VCC), U4.7 (CEP), U4.10 (CET), U4.16 (VCC), U5.7 (CEP), U5.10 (CET), U5.16 (VCC), U6.7 (CEP), U6.10 (CET), U6.16 (VCC), U7.1, U7.2, U7.4, U7.5, U7.6, U7.14 (VCC), U8.14 (VCC), U9.14 (VCC), U10.1, U10.2, U10.3, U10.14 (VCC), U11.14 (VCC), U12.6, U12.11, U12.12, U12.14 (VCC), U13.14 (VCC), U14.14 (VCC), U15.14 (VCC), U16.14 (VCC), U17.1, U17.14 (VCC), U18.14 (VCC), U19.14 (VCC), U20.11, U20.12, U20.14 (VCC), U21.7 (CEP), U21.16 (VCC), U22.15 (OEb), U22.16 (VCC), U23.7 (CEP), U23.10 (CET), U23.16 (VCC), U24.15 (OEb), U24.16 (VCC), U25.14 (VCC), U26.7 (CEP), U26.16 (VCC), U27.15 (OEb), U27.16 (VCC), U28.7 (CEP), U28.10 (CET), U28.16 (VCC), U29.15 (OEb), U29.16 (VCC), U30.20 (VCC), U31.1 (~MR), U31.3 (D0), U31.4 (D1), U31.5 (D2), U31.6 (D3), U31.7 (CEP), U31.10 (CET), U31.16 (VCC), U32.6 (E3), U32.16 (VCC), U33.16 (VCC), U34.16 (VCC), U35.16 (VCC), U36.16 (VCC), U37.16 (VCC), U38.16 (VCC), U39.16 (VCC), U40.16 (VCC), U41.16 (VCC), U42.6 (E3), U42.16 (VCC), U43.14 (V_{DD}), U44.14 (V_{DD}), U45.14 (V_{DD}), U46.14 (V_{DD}), U47.14 (V_{DD}), U48.14 (V_{DD}), U49.14 (V_{DD}), U50.14 (V_{DD}), U51.14 (V_{DD}), U52.14 (V_{DD}), U53.14 (V_{DD}), U54.14 (V_{DD}), U55.14 (V_{DD}), U56.14 (V_{DD}), U57.14 (V_{DD}), U58.14 (V_{DD}), U59.14 (VCC), U60.16 (VDD), U61.5, U61.14 (VCC), U62.6 (E3), U62.16 (VCC), U63.16 (VCC), U64.1, U64.2, U64.3, U64.14 (VCC), U65.1, U65.2, U65.14 (VCC), U66.14 (VCC), U68.16 (VCC), U69.1, U69.14 (VCC), U70.1 (A->B), U70.20 (VCC), U71.28 (VCC), U72.20 (VCC), U73.20 (VCC), U74.20 (VCC), U75.20 (VCC), U76.13, U76.14 (VCC), U77.20 (VCC), U78.7 (CEP), U78.10 (CET), U78.16 (VCC), U79.7 (CEP), U79.16 (VCC), U80.7 (CEP), U80.16 (VCC), U81.7 (CEP), U81.16 (VCC), U82.20 (VCC), U83.14 (VCC), U90.14 (VCC), U91.16 (VCC), U100.20 (VCC), U101.20 (VCC), U102.7 (CEP), U102.16 (VCC), U103.13, U103.14 (VCC), U104.14 (VCC), U105.6 (E3), U105.16 (VCC), U106.14 (VCC), U110.14 (VCC), U111.11, U111.12, U111.14 (VCC), U112.6, U112.11, U112.12, U112.14 (VCC), U113.6, U113.11, U113.12, U113.14 (VCC), U114.14 (VCC), U115.14 (VCC), U118.14 (VCC), U119.14 (VCC), U127.14 (VCC), U128.14 (VCC), U129.1, U129.14 (VCC), U136.14 (VCC), U137.14 (VCC)
/A0: J2.1, U72.2 (I0a)
/A1: J2.2, U72.17 (I3b)
/A2: J2.3, U72.4 (I1a)
/A3: J2.4, U72.6 (I2a)
/A4: J2.5, U72.15 (I2b)
/A5: J2.6, U72.8 (I3a)
/A6: J2.7, U72.13 (I1b)
/A7: J2.8, U72.11 (I0b)
/A8: J2.9, U73.2 (I0a)
/A9: J2.10, U73.4 (I1a)
/A10: J2.11, U73.15 (I2b)
/A11: J2.12, U73.6 (I2a)
/A12: J2.13, U73.13 (I1b)
/A13: J2.14, U90.2
/A14: J2.15, U90.10
/BitmapAddressRegister/CA0: U78.15 (TC), U79.10 (CET)
/BitmapAddressRegister/CA1: U79.15 (TC), U80.10 (CET)
/BitmapAddressRegister/CA2: U80.15 (TC), U81.10 (CET)
/BitmapAddressRegister/IBA0: J57.1, J58.1, U74.2 (I0a), U78.14 (Q0), U100.3 (D0)
/BitmapAddressRegister/IBA1: J57.2, J58.2, U74.17 (I3b), U78.13 (Q1), U100.4 (D1)
/BitmapAddressRegister/IBA2: J57.3, J58.3, U74.4 (I1a), U78.12 (Q2), U100.7 (D2)
/BitmapAddressRegister/IBA3: J57.4, J58.4, U74.15 (I2b), U78.11 (Q3), U100.8 (D3)
/BitmapAddressRegister/IBA4: J57.5, J58.5, U74.6 (I2a), U79.14 (Q0), U100.13 (D4)
/BitmapAddressRegister/IBA5: J57.6, J58.6, U74.13 (I1b), U79.13 (Q1), U100.14 (D5)
/BitmapAddressRegister/IBA6: J57.7, J58.7, U74.8 (I3a), U79.12 (Q2), U100.17 (D6)
/BitmapAddressRegister/IBA7: J57.8, J58.8, U74.11 (I0b), U79.11 (Q3), U100.18 (D7)
/BitmapAddressRegister/IBA8: J57.9, J58.9, U75.2 (I0a), U80.14 (Q0), U101.3 (D0)
/BitmapAddressRegister/IBA9: J57.10, J58.10, U75.15 (I2b), U80.13 (Q1), U101.4 (D1)
/BitmapAddressRegister/IBA10: J57.11, J58.11, U75.4 (I1a), U80.12 (Q2), U101.7 (D2)
/BitmapAddressRegister/IBA11: J57.12, J58.12, U75.13 (I1b), U80.11 (Q3), U101.8 (D3)
/BitmapAddressRegister/IBA12: J57.13, J58.13, U75.6 (I2a), U81.14 (Q0), U101.13 (D4)
/BitmapAddressRegister/IBA13: J57.14, J58.14, U75.11 (I0b), U81.13 (Q1), U101.14 (D5)
/BitmapAddressRegister/IBA14: J57.15, J58.15, U75.8 (I3a), U81.12 (Q2), U101.17 (D6)
/BitmapAddressRegister/RA0: U78.3 (D0), U100.2 (O0)
/BitmapAddressRegister/RA1: U78.4 (D1), U100.5 (O1)
/BitmapAddressRegister/RA2: U78.5 (D2), U100.6 (O2)
/BitmapAddressRegister/RA3: U78.6 (D3), U100.9 (O3)
/BitmapAddressRegister/RA4: U79.3 (D0), U100.12 (O4)
/BitmapAddressRegister/RA5: U79.4 (D1), U100.15 (O5)
/BitmapAddressRegister/RA6: U79.5 (D2), U100.16 (O6)
/BitmapAddressRegister/RA7: U79.6 (D3), U100.19 (O7)
/BitmapAddressRegister/RA8: U80.3 (D0), U101.2 (O0)
/BitmapAddressRegister/RA9: U80.4 (D1), U101.5 (O1)
/BitmapAddressRegister/RA10: U80.5 (D2), U101.6 (O2)
/BitmapAddressRegister/RA11: U80.6 (D3), U101.9 (O3)
/BitmapAddressRegister/RA12: U81.3 (D0), U101.12 (O4)
/BitmapAddressRegister/RA13: U81.4 (D1), U101.15 (O5)
/BitmapAddressRegister/RA14: U81.5 (D2), U101.16 (O6)
/BitmapAddressRegister/RC0: J61.2, U102.14 (Q0), U103.1
/BitmapAddressRegister/RC1: J61.3, U102.13 (Q1), U103.3
/BitmapAddressRegister/RC2: J61.4, U102.12 (Q2), U103.5
/BitmapAddressRegister/RC3: J61.5, U102.11 (Q3)
/BitmapAddressRegister/RR0: J61.6, U105.1 (A0)
/BitmapAddressRegister/RR1: J61.7, U105.2 (A1)
/BitmapAddressRegister/Reload: U78.9 (~PE), U79.9 (~PE), U80.9 (~PE), U81.9 (~PE), U104.8
/BitmapAddressRegister/~RC0: U103.2, U104.10, U106.2
/BitmapAddressRegister/~RC1: U103.4, U104.12, U106.5
/BitmapAddressRegister/~RC2: U103.6, U104.13, U106.10
/BitmapAddressRegister/~RRMR: J61.1, U100.11 (Cp), U101.11 (Cp), U102.1 (~MR), U104.6
/BitmapAddressRegister/~Reset2: U104.2, U106.3
/BitmapAddressRegister/~Reset4: U104.4, U106.6
/BitmapAddressRegister/~Reset8: U104.5, U106.8
/BitmapDataCounter/2T: U21.14 (Q0), U22.6 (I0a)
/BitmapDataCounter/4T: U21.13 (Q1), U22.5 (I1a)
/BitmapDataCounter/8T: U21.12 (Q2), U22.4 (I2a)
/BitmapDataCounter/16T: U21.11 (Q3), U22.3 (I3a)
/BitmapDataCounter/BPP0: J18.1, J47.1, J48.1, U24.14 (A0), U29.14 (A0), U32.1 (A0), U40.14 (S0), U41.14 (S0)
/BitmapDataCounter/BPP1: J18.2, J47.2, J48.2, U24.2 (A1), U29.2 (A1), U32.2 (A1), U40.2 (S1), U41.2 (S1)
/BitmapDataCounter/CPP0: J18.3, J47.3, U22.14 (A0), U27.14 (A0)
/BitmapDataCounter/CPP1: J18.4, J47.4, U22.2 (A1), U27.2 (A1)
/BitmapDataCounter/LoadEnable: U21.1 (~MR), U21.10 (CET), U23.1 (~MR), U118.2
/BitmapDataCounter/PT0: U22.7 (Za), U23.2 (CP), U24.3 (I3a)
/BitmapDataCounter/PT1: U23.14 (Q0), U24.4 (I2a)
/BitmapDataCounter/PT2: U23.13 (Q1), U24.5 (I1a)
/BitmapDataCounter/PT3: U23.12 (Q2), U24.6 (I0a)
/BitmapMemory/BA0: U71.10 (A0), U72.18 (O0a), U74.18 (O0a)
/BitmapMemory/BA1: U71.9 (A1), U72.3 (O3b), U74.3 (O3b)
/BitmapMemory/BA2: U71.8 (A2), U72.16 (O1a), U74.16 (O1a)
/BitmapMemory/BA3: U71.7 (A3), U72.14 (O2a), U74.5 (O2b)
/BitmapMemory/BA4: U71.6 (A4), U72.5 (O2b), U74.14 (O2a)
/BitmapMemory/BA5: U71.5 (A5), U72.12 (O3a), U74.7 (O1b)
/BitmapMemory/BA6: U71.4 (A6), U72.7 (O1b), U74.12 (O3a)
/BitmapMemory/BA7: U71.3 (A7), U72.9 (O0b), U74.9 (O0b)
/BitmapMemory/BA8: U71.25 (A8), U73.18 (O0a), U75.18 (O0a)
/BitmapMemory/BA9: U71.24 (A9), U73.16 (O1a), U75.5 (O2b)
/BitmapMemory/BA10: U71.21 (A10), U73.5 (O2b), U75.16 (O1a)
/BitmapMemory/BA11: U71.23 (A11), U73.14 (O2a), U75.7 (O1b)
/BitmapMemory/BA12: U71.2 (A12), U73.7 (O1b), U75.14 (O2a)
/BitmapMemory/BA13: U71.26 (A13), U73.12 (O3a), U75.9 (O0b)
/BitmapMemory/BA14: U71.1 (A14), U73.9 (O0b), U75.12 (O3a)
/BitmapMemory/BD0: J53.1, J54.1, U30.3 (D0), U70.18 (B0)
/BitmapMemory/BD1: J53.2, J54.2, U30.18 (D7), U70.17 (B1)
/BitmapMemory/BD2: J53.3, J54.3, U30.4 (D1), U70.16 (B2)
/BitmapMemory/BD3: J53.4, J54.4, U30.17 (D6), U70.15 (B3)
/BitmapMemory/BD4: J53.5, J54.5, U30.14 (D5), U70.14 (B4)
/BitmapMemory/BD5: J53.6, J54.6, U30.7 (D2), U70.13 (B5)
/BitmapMemory/BD6: J53.7, J54.7, U30.8 (D3), U70.12 (B6)
/BitmapMemory/BD7: J53.8, J54.8, U30.13 (D4), U70.11 (B7)
/BitmapMemory/D0: U70.2 (A0), U71.11 (Q0), U77.3 (O3b), U82.17 (I3b)
/BitmapMemory/D1: U70.3 (A1), U71.12 (Q1), U77.18 (O0a), U82.2 (I0a)
/BitmapMemory/D2: U70.4 (A2), U71.13 (Q2), U77.5 (O2b), U82.15 (I2b)
/BitmapMemory/D3: U70.5 (A3), U71.15 (Q3), U77.16 (O1a), U82.4 (I1a)
/BitmapMemory/D4: U70.6 (A4), U71.16 (Q4), U77.7 (O1b), U82.13 (I1b)
/BitmapMemory/D5: U70.7 (A5), U71.17 (Q5), U77.14 (O2a), U82.6 (I2a)
/BitmapMemory/D6: U70.8 (A6), U71.18 (Q6), U77.9 (O0b), U82.11 (I0b)
/BitmapMemory/D7: U70.9 (A7), U71.19 (Q7), U77.12 (O3a), U82.8 (I3a)
/BitmapPixelCounter/2T: U26.14 (Q0), U27.6 (I0a)
/BitmapPixelCounter/4T: U26.13 (Q1), U27.5 (I1a)
/BitmapPixelCounter/8T: U26.12 (Q2), U27.4 (I2a)
/BitmapPixelCounter/16T: U26.11 (Q3), U27.3 (I3a)
/BitmapPixelCounter/CountEnable: U26.1 (~MR), U26.10 (CET), U28.1 (~MR), U128.2
/BitmapPixelCounter/PT0: U27.7 (Za), U28.2 (CP), U29.3 (I3a)
/BitmapPixelCounter/PT1: U28.14 (Q0), U29.4 (I2a)
/BitmapPixelCounter/PT2: U28.13 (Q1), U29.5 (I1a)
/BitmapPixelCounter/PT3: U28.12 (Q2), U29.6 (I0a)
/BitmapPixelData/BMPalette0: J50.1, U40.7 (Za)
/BitmapPixelData/BMPalette1: J50.2, U40.9 (Zb)
/BitmapPixelData/BMPalette2: J50.3, U41.7 (Za)
/BitmapPixelData/BMPalette3: J50.4, U41.9 (Zb)
/BitmapPixelData/BPP1Palette0: U33.5 (Z), U40.6 (I0a)
/BitmapPixelData/BPP2Palette0: U34.5 (Z), U40.5 (I1a)
/BitmapPixelData/BPP2Palette1: U35.5 (Z), U40.11 (I1b)
/BitmapPixelData/BPP4Palette0: U36.5 (Z), U40.4 (I2a)
/BitmapPixelData/BPP4Palette1: U37.5 (Z), U40.12 (I2b)
/BitmapPixelData/BPP4Palette2: U38.5 (Z), U41.4 (I2a)
/BitmapPixelData/BPP4Palette3: U39.5 (Z), U41.12 (I2b)
/BitmapPixelData/D0: U30.2 (O0), U33.12 (I7), U34.1 (I3), U36.3 (I1)
/BitmapPixelData/D1: U30.19 (O7), U33.13 (I6), U35.1 (I3), U37.3 (I1)
/BitmapPixelData/D2: U30.5 (O1), U33.14 (I5), U34.2 (I2), U38.3 (I1)
/BitmapPixelData/D3: U30.16 (O6), U33.15 (I4), U35.2 (I2), U39.3 (I1)
/BitmapPixelData/D4: U30.15 (O5), U33.1 (I3), U34.3 (I1), U36.4 (I0)
/BitmapPixelData/D5: U30.6 (O2), U33.2 (I2), U35.3 (I1), U37.4 (I0)
/BitmapPixelData/D6: U30.9 (O3), U33.3 (I1), U34.4 (I0), U38.4 (I0)
/BitmapPixelData/D7: U30.12 (O4), U33.4 (I0), U35.4 (I0), U39.4 (I0)
/BitmapPixelData/DefaultPalette1: J49.2, U40.10 (I0b)
/BitmapPixelData/DefaultPalette2: J49.3, U41.5 (I1a), U41.6 (I0a)
/BitmapPixelData/DefaultPalette3: J49.4, U41.10 (I0b), U41.11 (I1b)
/BitmapPixelData/PT1: U31.14 (Q0), U33.10 (S1), U34.10 (S1), U35.10 (S1)
/BitmapPixelData/PT2: U31.13 (Q1), U33.9 (S2)
/BitmapPixelData/Pattern0: U32.15 (O0), U33.7 (~E)
/BitmapPixelData/Pattern1: U32.14 (O1), U34.7 (~E), U35.7 (~E)
/BitmapPixelData/Pattern2: U32.13 (O2), U36.7 (~E), U37.7 (~E), U38.7 (~E), U39.7 (~E)
/BitmapPixelData/~MR: U31.9 (~PE), U136.2
/ControlRegisters/PageSize0: U76.5, U90.4
/ControlRegisters/PageSize1: U76.9, U90.12
/ControlRegisters/~PageSize0: U76.6, U90.1
/ControlRegisters/~PageSize1: U76.8, U90.9
/ControlRegisters/~SelectRegister5: U25.9, U25.12
/FrameTiming/VSource0: J15.6, U42.1 (A0), U68.9 (S0)
/FrameTiming/VSource1: J15.5, U42.2 (A1), U68.7 (S1)
/FrameTiming/VSource2: J15.4, U42.3 (A2), U68.6 (S2)
/FrameTiming/X0: J5.1, J8.1, J12.1, U1.14 (Q0)
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

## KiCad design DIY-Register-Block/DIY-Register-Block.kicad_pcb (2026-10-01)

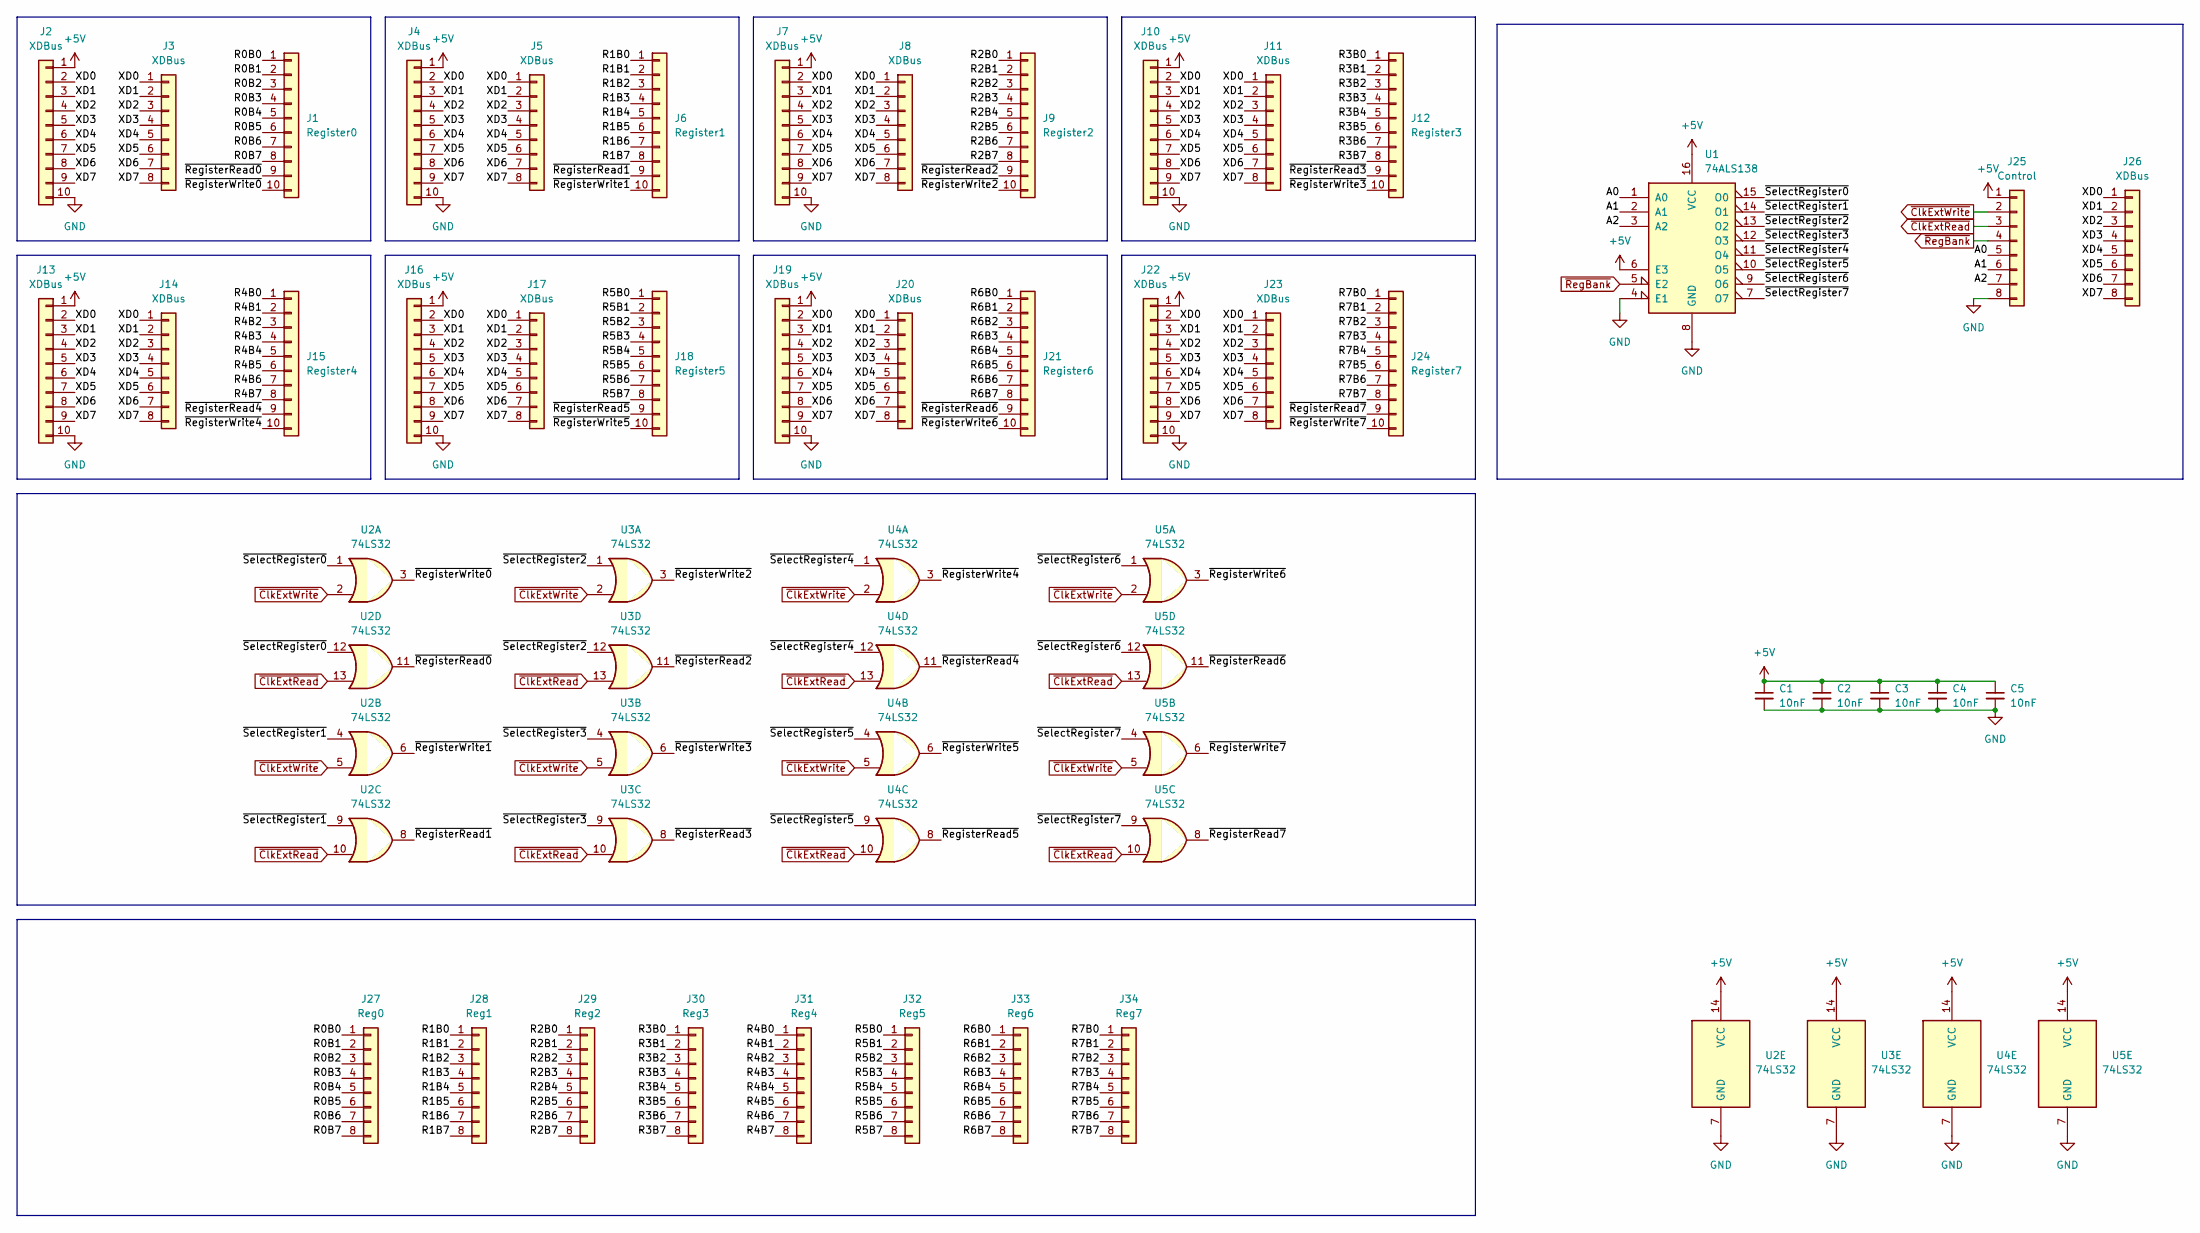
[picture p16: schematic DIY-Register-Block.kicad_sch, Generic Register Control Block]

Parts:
C1, C2, C3, C4, C5: 10nF; C_0603_1608Metric
J1: Register0; PinHeader_1x10_P1.27mm_Vertical
J2, J4, J7, J10, J13, J16, J19, J22: XDBus; PinHeader_1x10_P1.27mm_Vertical
J3, J5, J8, J11, J14, J17, J20, J23: XDBus; PinHeader_1x08_P1.27mm_Vertical
J6: Register1; PinHeader_1x10_P1.27mm_Vertical
J9: Register2; PinHeader_1x10_P1.27mm_Vertical
J12: Register3; PinHeader_1x10_P1.27mm_Vertical
J15: Register4; PinHeader_1x10_P1.27mm_Vertical
J18: Register5; PinHeader_1x10_P1.27mm_Vertical
J21: Register6; PinHeader_1x10_P1.27mm_Vertical
J24: Register7; PinHeader_1x10_P1.27mm_Vertical
J25: Control; PinHeader_1x08_P2.54mm_Vertical
J26: XDBus; PinHeader_1x08_P2.54mm_Vertical
J27: Reg0; PinHeader_1x08_P2.54mm_Vertical
J28: Reg1; PinHeader_1x08_P2.54mm_Vertical
J29: Reg2; PinHeader_1x08_P2.54mm_Vertical
J30: Reg3; PinHeader_1x08_P2.54mm_Vertical
J31: Reg4; PinHeader_1x08_P2.54mm_Vertical
J32: Reg5; PinHeader_1x08_P2.54mm_Vertical
J33: Reg6; PinHeader_1x08_P2.54mm_Vertical
J34: Reg7; PinHeader_1x08_P2.54mm_Vertical
U1: 74ALS138; SOIC-16_3.9x9.9mm_P1.27mm
U2, U3, U4: 74LS32; SO-14_3.9x8.65mm_P1.27mm
U5: 74LS32; SOIC-14_3.9x8.7mm_P1.27mm

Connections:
+5V: C1.1, C2.1, C3.1, C4.1, C5.1, J2.1, J4.1, J7.1, J10.1, J13.1, J16.1, J19.1, J22.1, J25.1, U1.6 (E3), U1.16 (VCC), U2.14 (VCC), U3.14 (VCC), U4.14 (VCC), U5.14 (VCC)
/A0: J25.5, U1.1 (A0)
/A1: J25.6, U1.2 (A1)
/A2: J25.7, U1.3 (A2)
/R0B0: J1.1, J27.1
/R0B1: J1.2, J27.2
/R0B2: J1.3, J27.3
/R0B3: J1.4, J27.4
/R0B4: J1.5, J27.5
/R0B5: J1.6, J27.6
/R0B6: J1.7, J27.7
/R0B7: J1.8, J27.8
/R1B0: J6.1, J28.1
/R1B1: J6.2, J28.2
/R1B2: J6.3, J28.3
/R1B3: J6.4, J28.4
/R1B4: J6.5, J28.5
/R1B5: J6.6, J28.6
/R1B6: J6.7, J28.7
/R1B7: J6.8, J28.8
/R2B0: J9.1, J29.1
/R2B1: J9.2, J29.2
/R2B2: J9.3, J29.3
/R2B3: J9.4, J29.4
/R2B4: J9.5, J29.5
/R2B5: J9.6, J29.6
/R2B6: J9.7, J29.7
/R2B7: J9.8, J29.8
/R3B0: J12.1, J30.1
/R3B1: J12.2, J30.2
/R3B2: J12.3, J30.3
/R3B3: J12.4, J30.4
/R3B4: J12.5, J30.5
/R3B5: J12.6, J30.6
/R3B6: J12.7, J30.7
/R3B7: J12.8, J30.8
/R4B0: J15.1, J31.1
/R4B1: J15.2, J31.2
/R4B2: J15.3, J31.3
/R4B3: J15.4, J31.4
/R4B4: J15.5, J31.5
/R4B5: J15.6, J31.6
/R4B6: J15.7, J31.7
/R4B7: J15.8, J31.8
/R5B0: J18.1, J32.1
/R5B1: J18.2, J32.2
/R5B2: J18.3, J32.3
/R5B3: J18.4, J32.4
/R5B4: J18.5, J32.5
/R5B5: J18.6, J32.6
/R5B6: J18.7, J32.7
/R5B7: J18.8, J32.8
/R6B0: J21.1, J33.1
/R6B1: J21.2, J33.2
/R6B2: J21.3, J33.3
/R6B3: J21.4, J33.4
/R6B4: J21.5, J33.5
/R6B5: J21.6, J33.6
/R6B6: J21.7, J33.7
/R6B7: J21.8, J33.8
/R7B0: J24.1, J34.1
/R7B1: J24.2, J34.2
/R7B2: J24.3, J34.3
/R7B3: J24.4, J34.4
/R7B4: J24.5, J34.5
/R7B5: J24.6, J34.6
/R7B6: J24.7, J34.7
/R7B7: J24.8, J34.8
/XD0: J2.2, J3.1, J4.2, J5.1, J7.2, J8.1, J10.2, J11.1, J13.2, J14.1, J16.2, J17.1, J19.2, J20.1, J22.2, J23.1, J26.1
/XD1: J2.3, J3.2, J4.3, J5.2, J7.3, J8.2, J10.3, J11.2, J13.3, J14.2, J16.3, J17.2, J19.3, J20.2, J22.3, J23.2, J26.2
/XD2: J2.4, J3.3, J4.4, J5.3, J7.4, J8.3, J10.4, J11.3, J13.4, J14.3, J16.4, J17.3, J19.4, J20.3, J22.4, J23.3, J26.3
/XD3: J2.5, J3.4, J4.5, J5.4, J7.5, J8.4, J10.5, J11.4, J13.5, J14.4, J16.5, J17.4, J19.5, J20.4, J22.5, J23.4, J26.4
/XD4: J2.6, J3.5, J4.6, J5.5, J7.6, J8.5, J10.6, J11.5, J13.6, J14.5, J16.6, J17.5, J19.6, J20.5, J22.6, J23.5, J26.5
/XD5: J2.7, J3.6, J4.7, J5.6, J7.7, J8.6, J10.7, J11.6, J13.7, J14.6, J16.7, J17.6, J19.7, J20.6, J22.7, J23.6, J26.6
/XD6: J2.8, J3.7, J4.8, J5.7, J7.8, J8.7, J10.8, J11.7, J13.8, J14.7, J16.8, J17.7, J19.8, J20.7, J22.8, J23.7, J26.7
/XD7: J2.9, J3.8, J4.9, J5.8, J7.9, J8.8, J10.9, J11.8, J13.9, J14.8, J16.9, J17.8, J19.9, J20.8, J22.9, J23.8, J26.8
/~RegisterRead0: J1.9, U2.11
/~RegisterRead1: J6.9, U2.8
/~RegisterRead2: J9.9, U3.11
/~RegisterRead3: J12.9, U3.8
/~RegisterRead4: J15.9, U4.11
/~RegisterRead5: J18.9, U4.8
/~RegisterRead6: J21.9, U5.11
/~RegisterRead7: J24.9, U5.8
/~RegisterWrite0: J1.10, U2.3
/~RegisterWrite1: J6.10, U2.6
/~RegisterWrite2: J9.10, U3.3
/~RegisterWrite3: J12.10, U3.6
/~RegisterWrite4: J15.10, U4.3
/~RegisterWrite5: J18.10, U4.6
/~RegisterWrite6: J21.10, U5.3
/~RegisterWrite7: J24.10, U5.6
/~SelectRegister0: U1.15 (O0), U2.1, U2.12
/~SelectRegister1: U1.14 (O1), U2.4, U2.9
/~SelectRegister2: U1.13 (O2), U3.1, U3.12
/~SelectRegister3: U1.12 (O3), U3.4, U3.9
/~SelectRegister4: U1.11 (O4), U4.1, U4.12
/~SelectRegister5: U1.10 (O5), U4.4, U4.9
/~SelectRegister6: U1.9 (O6), U5.1, U5.12
/~SelectRegister7: U1.7 (O7), U5.4, U5.9
GND: C1.2, C2.2, C3.2, C4.2, C5.2, J2.10, J4.10, J7.10, J10.10, J13.10, J16.10, J19.10, J22.10, J25.8, U1.4 (E1), U1.8 (GND), U2.7 (GND), U3.7 (GND), U4.7 (GND), U5.7 (GND)
~ClkExtRead: J25.3, U2.10, U2.13, U3.10, U3.13, U4.10, U4.13, U5.10, U5.13
~ClkExtWrite: J25.2, U2.2, U2.5, U3.2, U3.5, U4.2, U4.5, U5.2, U5.5
~RegBank: J25.4, U1.5 (E2)

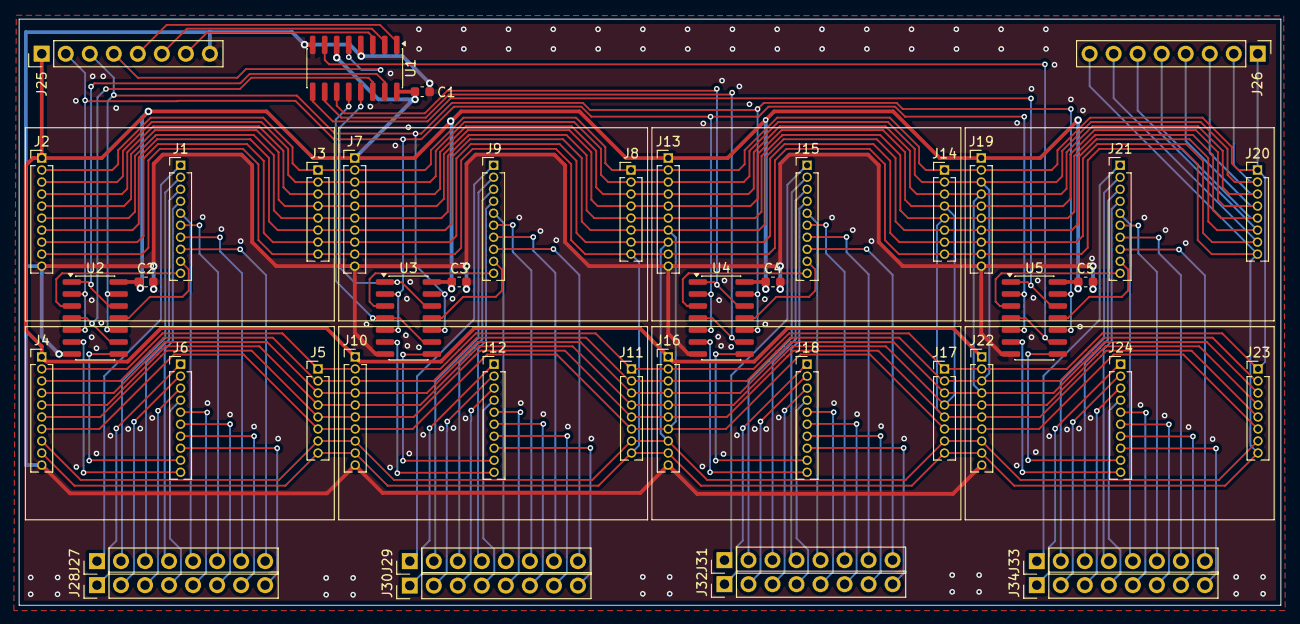
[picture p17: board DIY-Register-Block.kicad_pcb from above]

Board: 2 copper layers, 133.4 x 62.0 mm, 44 parts (0 on the bottom side), 104 nets.

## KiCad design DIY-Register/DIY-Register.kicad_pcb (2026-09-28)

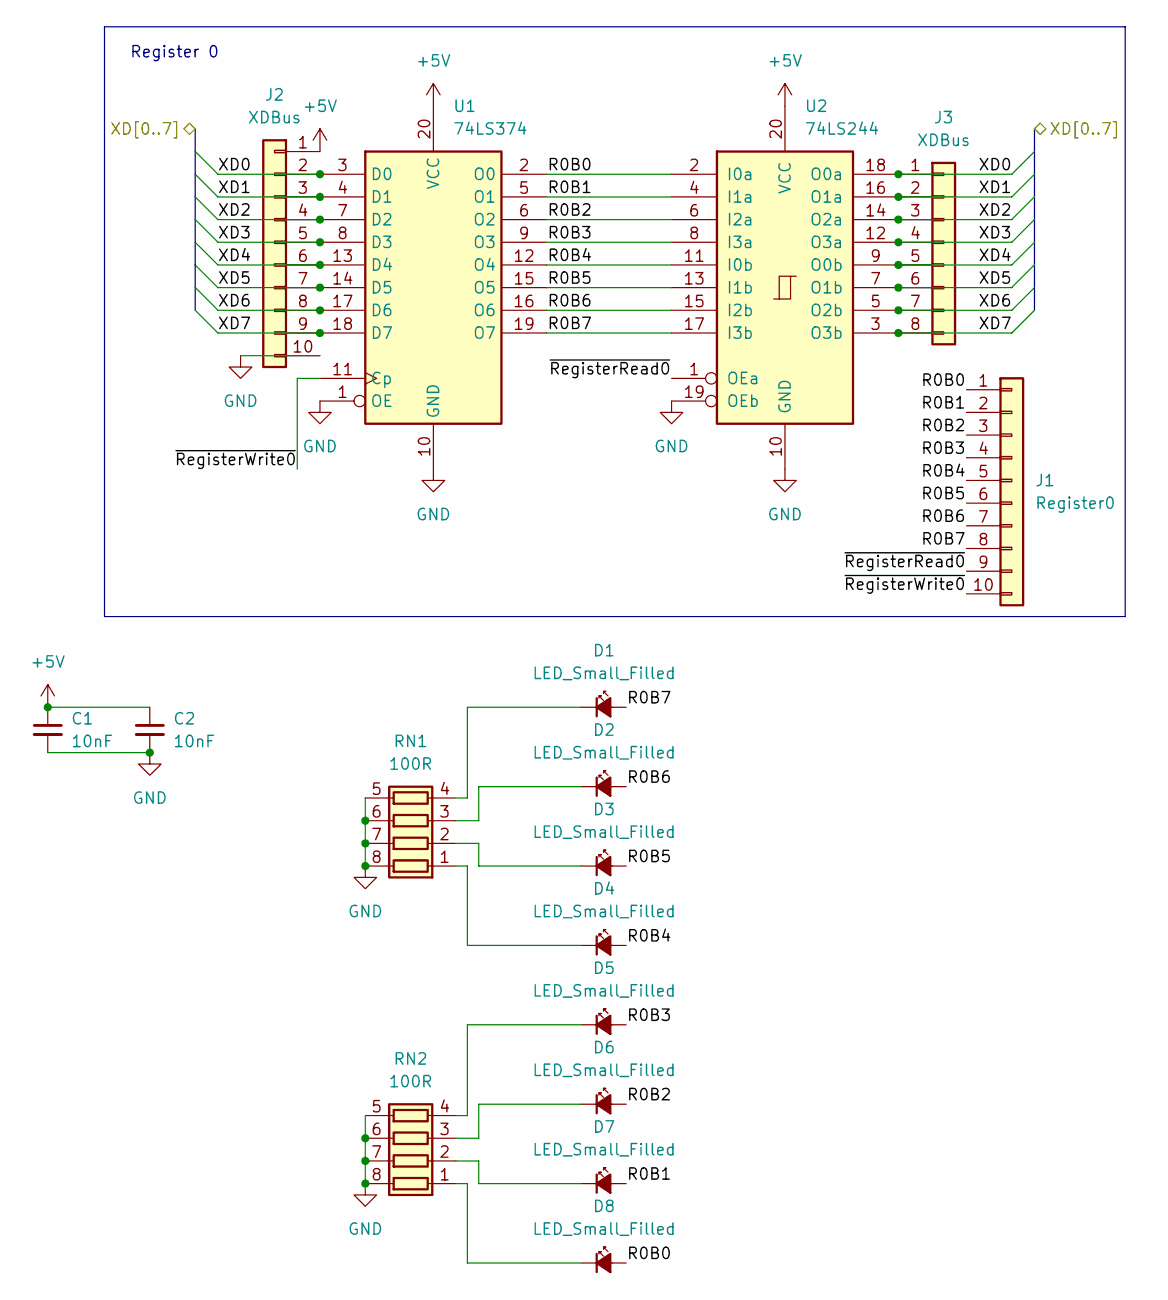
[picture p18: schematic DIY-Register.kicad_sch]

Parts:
C1, C2: 10nF; C_0603_1608Metric
D1, D2, D3, D4, D5, D6, D7, D8: LED_Small_Filled; LED_0603_1608Metric
J1: Register0; PinHeader_1x10_P1.27mm_Vertical
J2: XDBus; PinHeader_1x10_P1.27mm_Vertical
J3: XDBus; PinHeader_1x08_P1.27mm_Vertical
RN1, RN2: 100R; R_Array_Concave_4x0402
U1: 74LS374; SO-20_5.3x12.6mm_P1.27mm
U2: 74LS244; SO-20_5.3x12.6mm_P1.27mm

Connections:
+5V: C1.1, C2.1, J2.1, U1.20 (VCC), U2.20 (VCC)
/R0B0: D8.2 (A), J1.1, U1.2 (O0), U2.2 (I0a)
/R0B1: D7.2 (A), J1.2, U1.5 (O1), U2.4 (I1a)
/R0B2: D6.2 (A), J1.3, U1.6 (O2), U2.6 (I2a)
/R0B3: D5.2 (A), J1.4, U1.9 (O3), U2.8 (I3a)
/R0B4: D4.2 (A), J1.5, U1.12 (O4), U2.11 (I0b)
/R0B5: D3.2 (A), J1.6, U1.15 (O5), U2.13 (I1b)
/R0B6: D2.2 (A), J1.7, U1.16 (O6), U2.15 (I2b)
/R0B7: D1.2 (A), J1.8, U1.19 (O7), U2.17 (I3b)
/XD0: J2.2, J3.1, U1.3 (D0), U2.18 (O0a)
/XD1: J2.3, J3.2, U1.4 (D1), U2.16 (O1a)
/XD2: J2.4, J3.3, U1.7 (D2), U2.14 (O2a)
/XD3: J2.5, J3.4, U1.8 (D3), U2.12 (O3a)
/XD4: J2.6, J3.5, U1.13 (D4), U2.9 (O0b)
/XD5: J2.7, J3.6, U1.14 (D5), U2.7 (O1b)
/XD6: J2.8, J3.7, U1.17 (D6), U2.5 (O2b)
/XD7: J2.9, J3.8, U1.18 (D7), U2.3 (O3b)
/~RegisterRead0: J1.9, U2.1 (OEa)
/~RegisterWrite0: J1.10, U1.11 (Cp)
GND: C1.2, C2.2, J2.10, RN1.5 (R4.2), RN1.6 (R3.2), RN1.7 (R2.2), RN1.8 (R1.2), RN2.5 (R4.2), RN2.6 (R3.2), RN2.7 (R2.2), RN2.8 (R1.2), U1.1 (OE), U1.10 (GND), U2.10 (GND), U2.19 (OEb)
unnamed: D1.1 (K), RN1.4 (R4.1)
unnamed: D2.1 (K), RN1.3 (R3.1)
unnamed: D3.1 (K), RN1.2 (R2.1)
unnamed: D4.1 (K), RN1.1 (R1.1)
unnamed: D5.1 (K), RN2.4 (R4.1)
unnamed: D6.1 (K), RN2.3 (R3.1)
unnamed: D7.1 (K), RN2.2 (R2.1)
unnamed: D8.1 (K), RN2.1 (R1.1)

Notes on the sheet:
Register 0

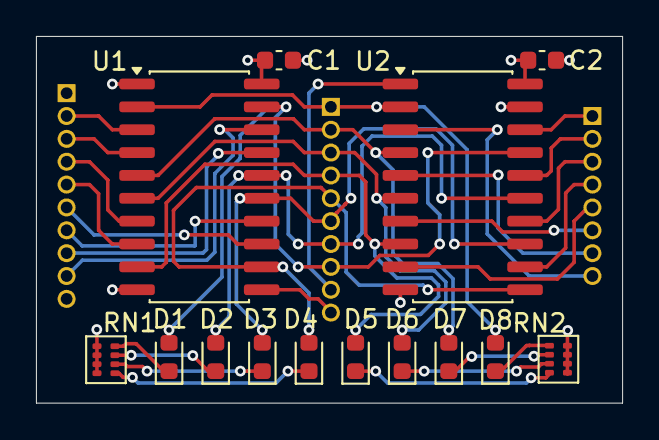
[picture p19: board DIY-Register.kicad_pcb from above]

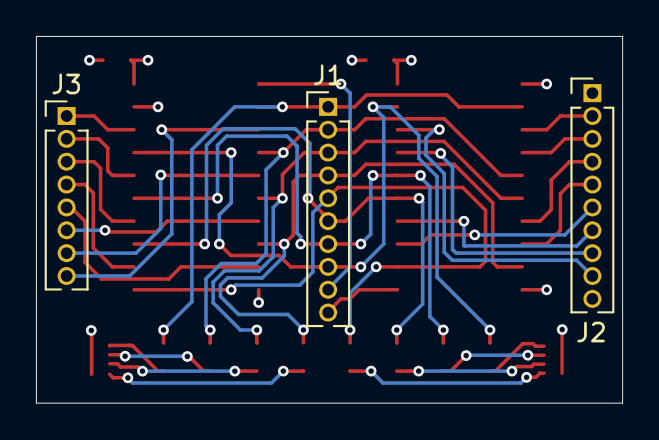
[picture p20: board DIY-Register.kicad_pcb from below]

Board: 4 copper layers, 32.6 x 20.4 mm, 17 parts (3 on the bottom side), 28 nets.

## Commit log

2026-09-20 provide annotation on modules
    [AddressReguster.kicad_sch, BitmaPixelData.kicad_sch, BitmapDataCounter.kicad_sch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]
2026-09-20 introduce PDF output from schematics
    [DIY-Video.kicad_sch, PaletteMux.kicad_sch]
2026-09-21 fix position counter Y reset logic
    [DIY-Video.kicad_sch, Interface0.kicad_sch, xycounter.kicad_sch]
2026-09-21 fix x/y counters to reset at the correct positions
    [AddressReguster.kicad_sch, xycounter.kicad_sch]
2026-09-21 revise position counter
    [viewport.kicad_sch, xycounter.kicad_sch]
2026-09-23 test (and fix) BitmapPixelData
    [AddressReguster.kicad_sch, BitmaPixelData.kicad_sch, viewport.kicad_sch]
2026-09-24 refine bus contention solution for host interface
    [Interface0.kicad_sch, bitmapMemory.kicad_sch, controlRegisters.kicad_sch]
2026-09-24 update pdf of schematic
2026-09-25 isolate each schematic function for testing
    [BitmapDataCounter.kicad_sch, DIY-Video.kicad_pcb, DIY-Video.kicad_sch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]
2026-09-27 rework schematic isolation
    [BitmapDataCounter.kicad_sch, BitmapPixelCounter.kicad_sch, DIY-Video.kicad_pcb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]
2026-09-28 spin register out as separate board
    [AddressReguster.kicad_sch, BitmaPixelData.kicad_sch, DIY-Register.kicad_pcb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]
2026-09-30 spin out block of 8 registers
    [DIY-Register-Block.kicad_pcb, DIY-Register-Block.kicad_sch]
2026-10-01 refine main board layout
    [BitmapPixelCounter.kicad_sch, DIY-Register-Block.kicad_pcb, DIY-Video.kicad_pcb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]
2026-10-04 tighten layout for final sizing
    [AddressReguster.kicad_sch, BitmaPixelData.kicad_sch, BitmapDataCounter.kicad_sch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]
